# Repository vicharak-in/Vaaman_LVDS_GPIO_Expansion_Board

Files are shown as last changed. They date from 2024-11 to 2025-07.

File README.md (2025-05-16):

# Vaaman_UART_Expansion_Board

GPIO HAT 1:

LVDS RX and TX from Vaaman configure as a GPIO of this HAT. total 80 GPIOs are availabe in HAT can be configure form Vaaman LVDS.

voltage level of signal: 3.3V

Level translator Part number: TXB0108DQSR

LVDS connector part number: DF40C-60DP-0.4V(51)

Vaaman and HAT Connection: Flex cable

Power input: Vaaman Header 





NOT tested Yet(GPIO HAT 1).

GPIO HAT 2:

LVDS RX and TX from Vaaman configure as a GPIO of this HAT. total 80 GPIOs are availabe in HAT can be configure form Vaaman LVDS.

voltage level of signal: 3.3V & 1.8V (using jumper)

Level translator Part number: TXB0108DQSR

LVDS connector part number: DF40C-60DP-0.4V(51)

Vaaman and HAT Connection: Flex cable

Power input: Vaaman Header or Type-C 





Power up instructions:

Vaaman LVDS GPIO HAT can Power by two Options: 

Option 1: Using Female to Female Jumper From Vaaman Header to GPIO Hat Header

Vaaman Header 5V and GND:



GPIO HAT Header:



Working Properly.

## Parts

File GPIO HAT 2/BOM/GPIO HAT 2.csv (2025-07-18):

Designator | Description | Value | Manufacturer Part Number | Type | Vicharak-PN | Footprint | Case/Package | Quantity
C10, C11, C19, C20, C21, C22, C23, C24, C25, C26, C27, C28, C29, C30, C31, C32, C33, C34, C35, C36, C37, C38 | 100nF, 25V, X5R, ±10%, 0402, Multilayer Ceramic Capacitor - SMD/SMT | 100nF | CL05A104KA5NNNC | Capacitor | V001480 | CAP_0402 | 402 | 22
C2, C3, C9, C13, C14, C6, C7, C17, C18 | 100nF, 25V, X7R, ±10%, 0603, Multilayer Ceramic Capacitors | 100nF | CL10B104KA8NNNC | Capacitor | V001603 | CAP_0603 | 603 | 9
C1, C8, C12, C5, C16 | 1uF, 25V, X5R, ±10%, 0603, Multilayer Ceramic Capacitor - SMD/SMT | 1uF | CL10A105KA8NNNC | Capacitor | V001450 | CAP_0603 | 603 | 5
C4, C15 | 100pF, 50V, NP0, ±5%, 0402, Multilayer Ceramic Ca...tors MLCC - SMD/SMT | 100pF | CC0402JRNPO9BN101 | Capacitor | V000090 | CAP_0402 | 402 | 2
R8, R9, R10, R11, R12, R13, R14, R15, R16, R17, R7 | 10KOhm, ±1%, 62.5mW, 0402, Chip Resisto | 10K | 0402WGF1002TCE | Resistor | V000011 | RES_0402 | 402 | 11
R1, R6 | 100KOhm, ±1%, 1/16W, 0402, Resistor | 100K | RC0402FR-07100KL | Resistor | V000404 | RES_0402 | 402 | 2
R2 | 22.1KOhm, ±1%, 62.5mW, 0402, Chip Resisto | 22.1K | 0402WGF2212TCE | Resistor | V000235 | RES_0402 | 402 | 1
R3 | 20KOhm, ±1%, 62.5mW, 0402, Resistor | 20K | 0402WGF2002TCE | Resistor | V000408 | RES_0402 | 402 | 1
R5 | 4.99KOhm, ±1% 62.5mW, 0402, Chip Resistor | 4.99K | 0402WGF4991TCE | Resistor | V000258 | RES_0402 | 402 | 1
R7 | 49.9KOhm, ±1%, 62.5mW, 0402, Resisto | 49.9K | 0402WGF4992TCE | Resistor | V001610 | RES_0402 | 402 | 1
R18, R19 | 5.1KOhm, ±1%, 62.5mW, 0402, Resistor | 5.1K | 0402WGF5101TCE | Resistor | V000399 | RES_0402 | 402 | 2
L1, L2 | 3.3uH, 40mOhm, 2.4A, 3.3A, 30%, Power Inductors | 3.3uH | GCNR4030-3R3NC | Inductor | V001278 | IND | IND | 2
U4, U5, U6, U7, U8, U9, U10, U11, U12, U13 | Voltage Level Translator Bidirectional 1 Circuit 8 Channel 100Mbps 20-USON (4x2) |  | TXB0108DQSR | IC | V001766 | USON20 | USON20 | 10
U1, U3 | Buck, Input 2.5V~5.5V, 1A, SOT-23-5, DC-DC Converter |  | SY8088IAAC | IC | V001502 | SOT23-5 | SOT23-5 | 2
U2 | 1.6-V to 5.5-V, 4-A Low IQ Power Mux With Manual and Priority Switchover |  | TPS2117 | IC | V001701 | SOT8 | SOT-8 | 1
J1 | Type-C 5A USB 3.1 1 260? Surface Mount 6P Female ...5? Gold Copper Alloy SMD USB Connector |  | U262-061N-4BVC11 | Connector | V000570 |  |  | 1
J3, J4 | 0.4mm 2 60 -35?~+85? Brick nogging male 300mA SMD...m Mezzanine Connector |  | DF40C-60DP-0.4V(51) | Connector | V000472 | DF40C-60DP-0.4V(51) |  | 2
J1, J2, J3, J4, J5, J6, J7, J8, J9, J10, J11, J12, J13, J14, J15, J16, J17, J18, J19, J20 | Connector Header Through Hole 6 position 0.100" (2.54mm) |  | 2541WV-06P | Connector | V002463 | 01x06 HEADER |  | 20
JM1, JM2, JM3, JM4, JM5 |  | PinHeader_1x03_P2.54mm_Vertical | 2541WV-03P | Connector | V002464 | 01x03 HEADER |  | 5
J24 | Gold Through Hole Pin Header 2.54mm 4Pin 2x2Pin |  | 2541WV-2x02P | Connector | V002465 | 02X02 HEADER |  | 1
PCB | GPIO HAT BLANK PCB V1.3 |  |  |  | V002371 |  |  | 1

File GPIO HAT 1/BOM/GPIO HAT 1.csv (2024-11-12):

Id | Designator | Footprint | Quantity | Designation | Supplier and ref
1 | J2,J14,J1,J9,J17,J13,J10,J7,J12,J15,J8,J16,J5,J19,J3,J11,J4,J20,J18,J6 | 01x05 Header 2.54mm | 20 | Conn_01x05
2 | R6,R3,R10,R8,R5,R1,R7,R4,R9,R2 | RES0402_10K | 10 | 10K
3 | U10,U6,U7,U1,U2,U9,U8,U5,U4,U3 | TXB0108DQSR | 10 | TXB0108DQSR
4 | J23,J24 | 2x20 header | 2 | 2.54-2*20PPC104
5 | ,,, | HOLEE | 4 | HOLE
6 | C9,C6,C14,C19,C18,C4,C10,C3,C5,C20,C15,C16,C8,C1,C11,C2,C7,C12,C13,C17 | CAP0402 | 20 | 0.1uF
7 | J21,J22 | LVDS2 | 2 | ~

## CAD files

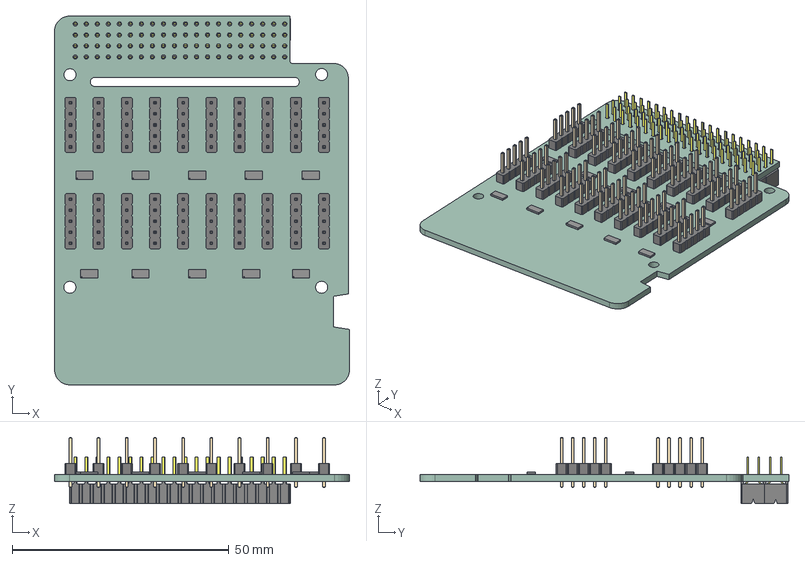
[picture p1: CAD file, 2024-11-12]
GPIO HAT 1/GPIO HAT 1.step
68.0 x 85.0 x 15.3 mm
PinHeader_1x05_P254mm_Vertical x 20
DQS20 x 10
ces-120-02-g-d x 2
_autosave-VAAMAN_KICAD_PCB

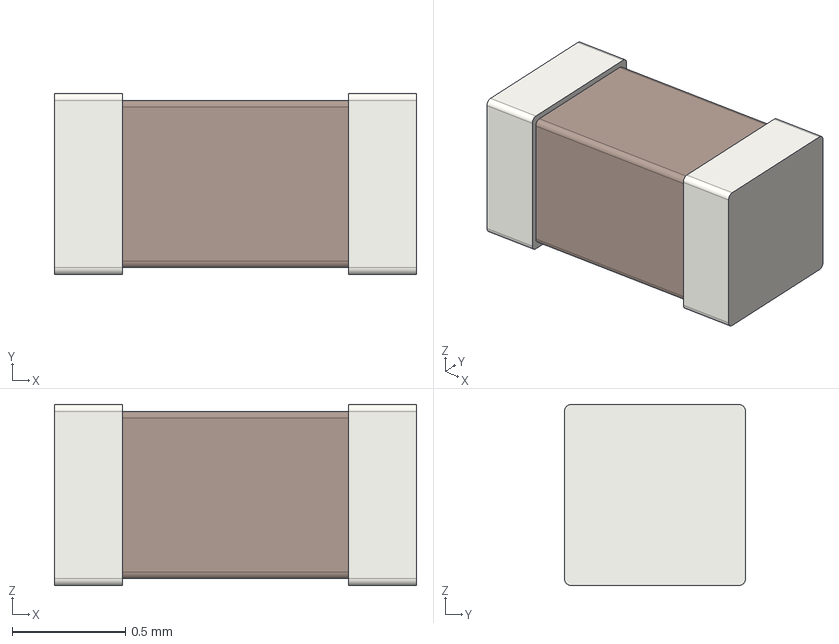
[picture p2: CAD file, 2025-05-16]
GPIO HAT 2/Component 3D File/C_0603_1608Metric.step
1.60 x 0.8 x 0.8 mm

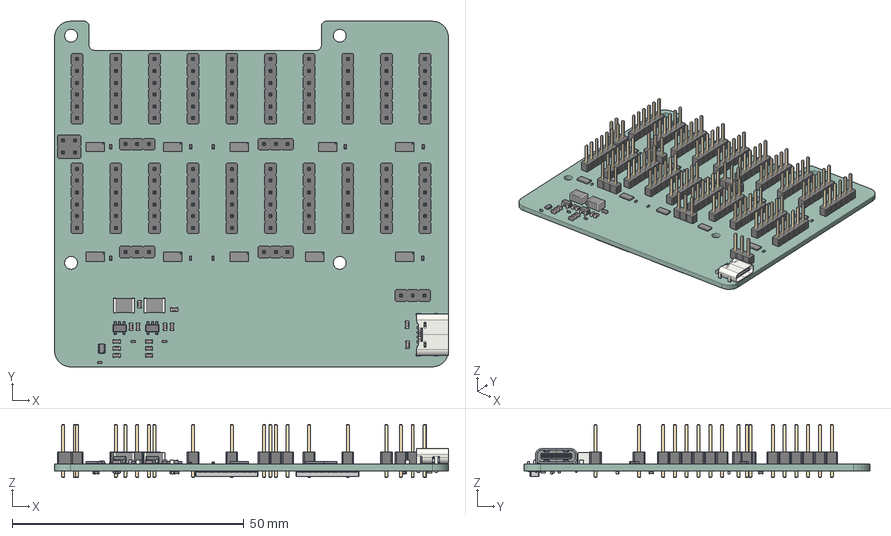
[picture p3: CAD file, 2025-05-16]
GPIO HAT 2/VAAMAN KICAD 2.step
85.0 x 74.6 x 11.5 mm
R_0402_1005Metric x 13
C_0603_1608Metric x 14
DQS20 x 10
C_0402_1005Metric x 24
PinHeader_1x06_P254mm_Vertical x 20
PinHeader_1x03_P254mm_Vertical x 5
L_1812_4532Metric x 2
PinHeader_2x02_P254mm_Vertical
SOT_23_5 x 2
USB_C_Receptacle_GCT_USB4125-xx-x_6P_TopMnt_Horizontal
TPS2116DRLR
DF40C-40DP-0.4V.1 x 2
GPIO HAT 2_PCB

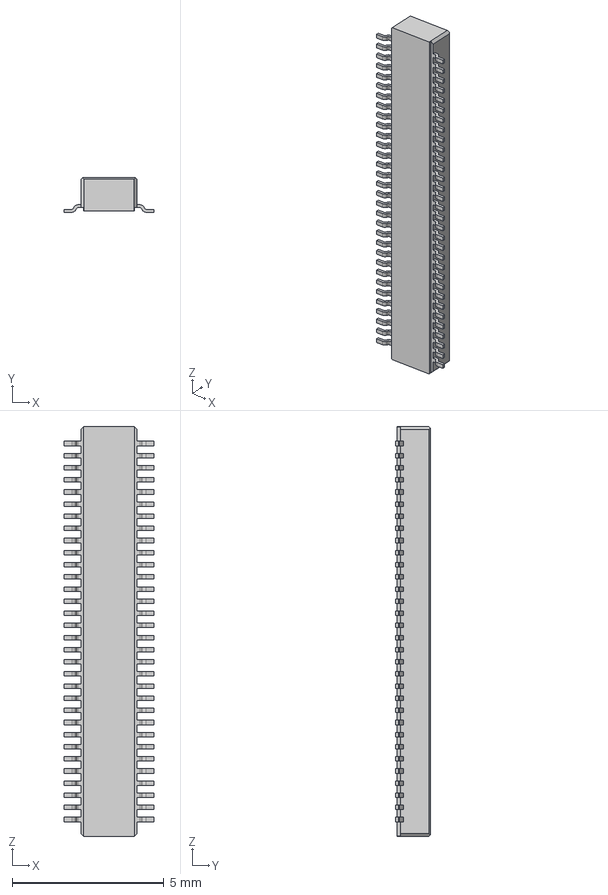
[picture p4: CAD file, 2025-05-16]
GPIO HAT 2/Component 3D File/DF40C-60DP.stp
2.97 x 1.14 x 13.5 mm

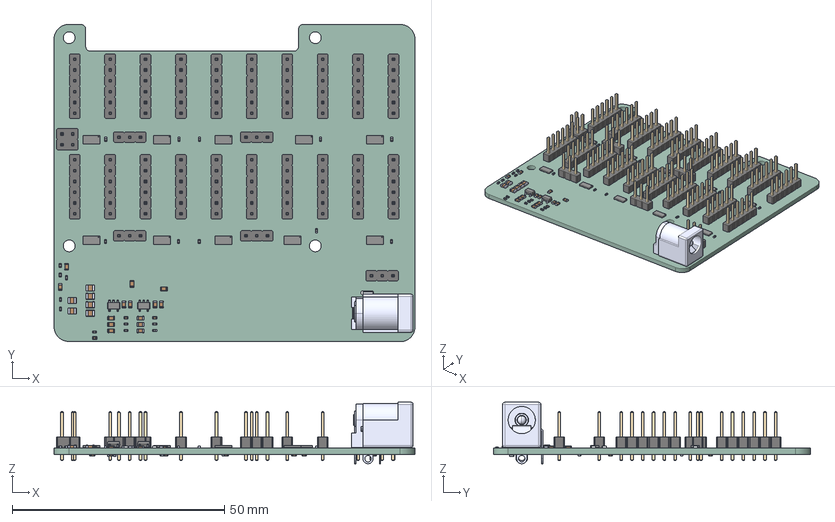
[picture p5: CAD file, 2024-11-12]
GPIO HAT 2/GPIO HAT 2.step
85.0 x 74.7 x 14.5 mm
SR0402JR-7W10RL x 22
CL10B105MO8NNWC x 14
DQS20 x 10
PinHeader_1x06_P254mm_Vertical x 20
PinHeader_1x03_P254mm_Vertical x 5
VJ0805A221KXRAT5Z x 6
VJ0402D180JXBAJ x 24
PinHeader_2x02_P254mm_Vertical
MAX6316LUK29BX_V+T x 2
VAAMAN KICAD 2_PCB

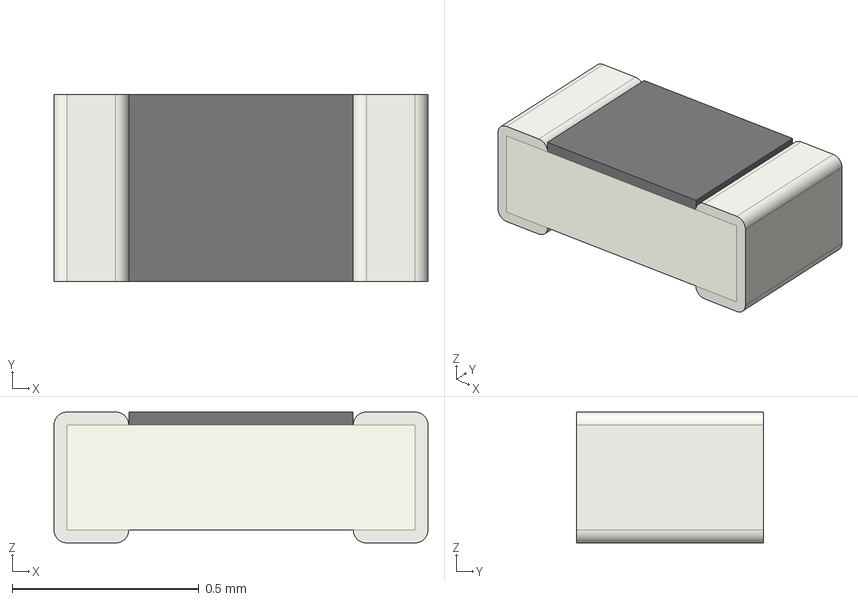
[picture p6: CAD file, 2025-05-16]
GPIO HAT 2/Component 3D File/R_0402_1005Metric.step
1.00 x 0.5 x 0.35 mm

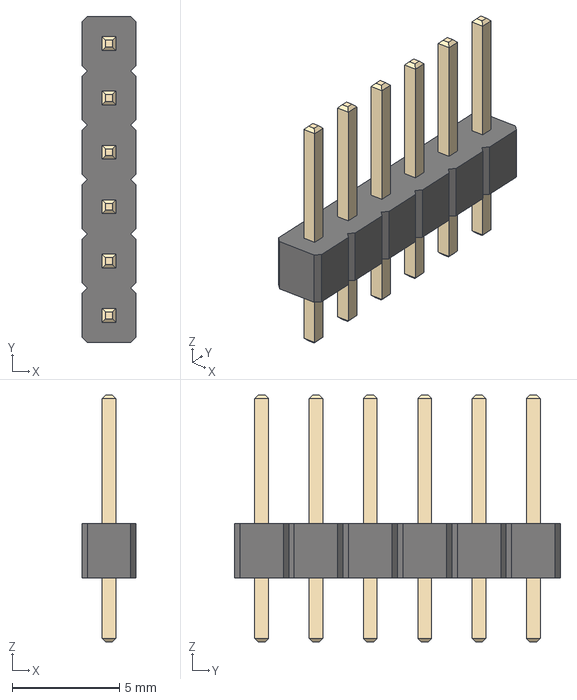
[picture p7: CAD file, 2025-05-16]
GPIO HAT 2/Component 3D File/PinHeader_1x06_P2.54mm_Vertical.step
2.54 x 15.2 x 11.5 mm

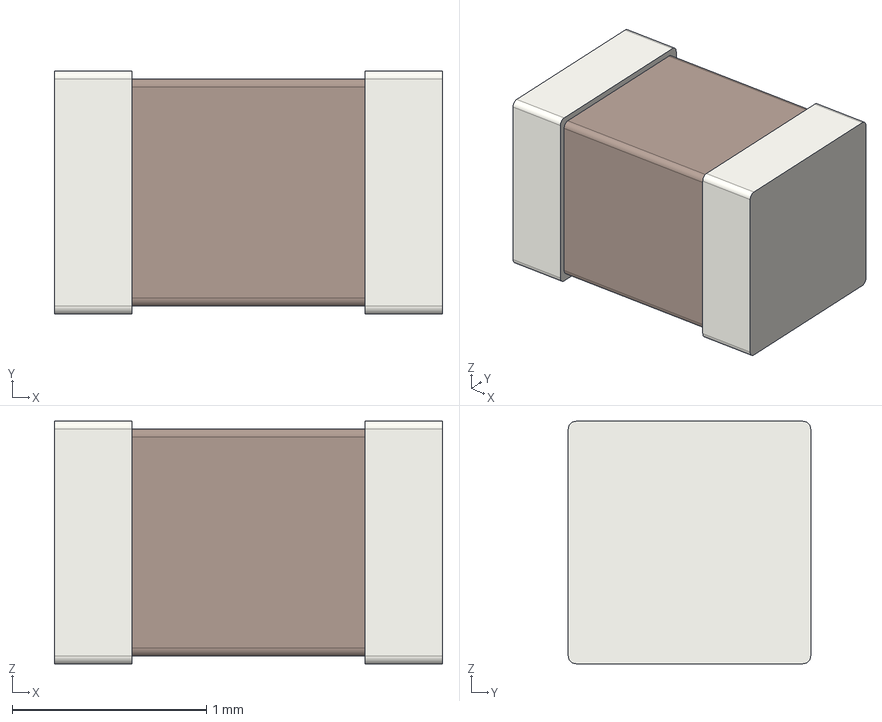
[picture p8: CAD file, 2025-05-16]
GPIO HAT 2/Component 3D File/C_0805_2012Metric.step
2.00 x 1.25 x 1.25 mm

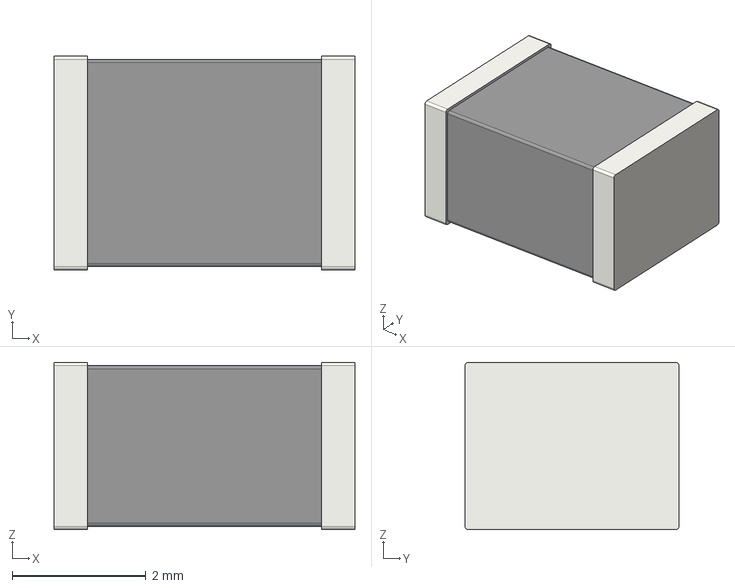
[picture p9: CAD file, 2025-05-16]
GPIO HAT 2/Component 3D File/L_1812_4532Metric.step
4.50 x 3.20 x 2.50 mm

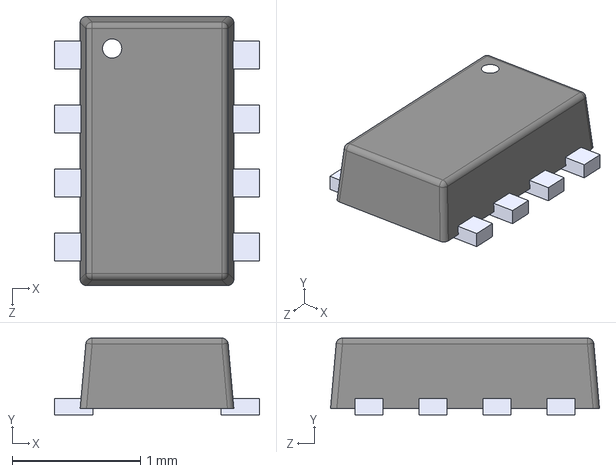
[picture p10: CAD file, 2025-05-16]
GPIO HAT 2/Component 3D File/TPS2117DRLR.STEP
1.60 x 0.6 x 2.10 mm

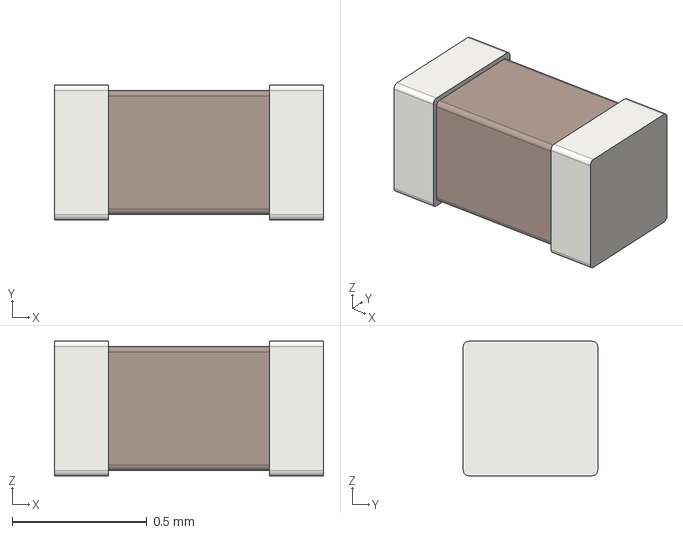
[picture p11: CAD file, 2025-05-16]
GPIO HAT 2/Component 3D File/C_0402_1005Metric.step
1.00 x 0.5 x 0.5 mm

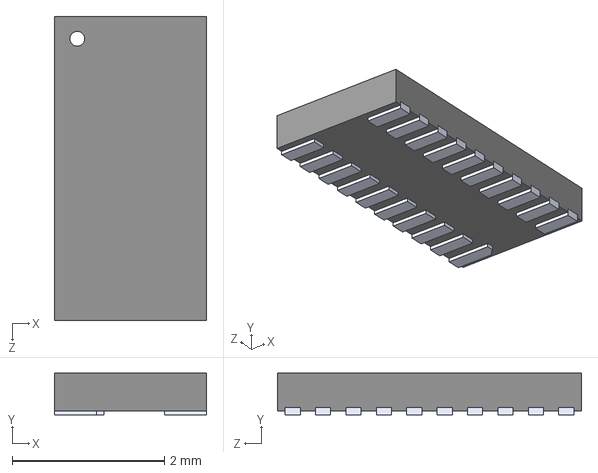
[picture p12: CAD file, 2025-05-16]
GPIO HAT 2/Component 3D File/TXB0108DQSR.STEP
2.00 x 0.55 x 4.00 mm

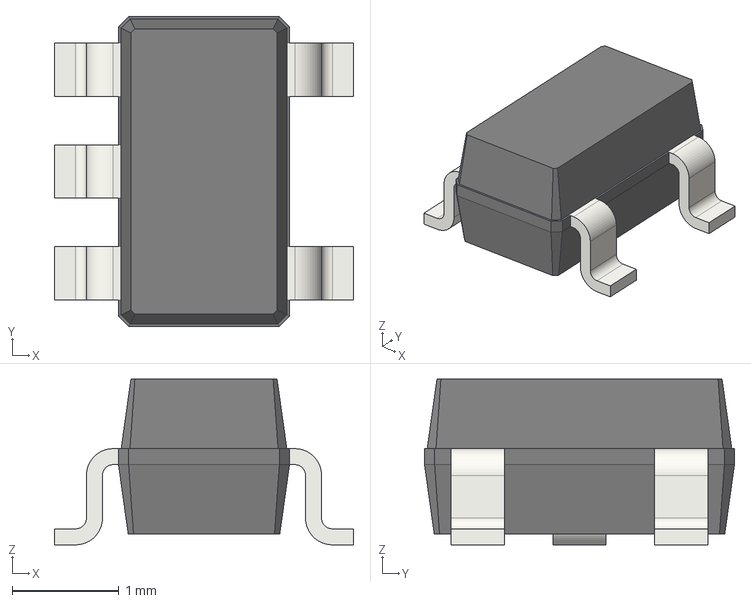
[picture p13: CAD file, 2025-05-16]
GPIO HAT 2/Component 3D File/SOT-23-5.step
2.80 x 2.90 x 1.55 mm

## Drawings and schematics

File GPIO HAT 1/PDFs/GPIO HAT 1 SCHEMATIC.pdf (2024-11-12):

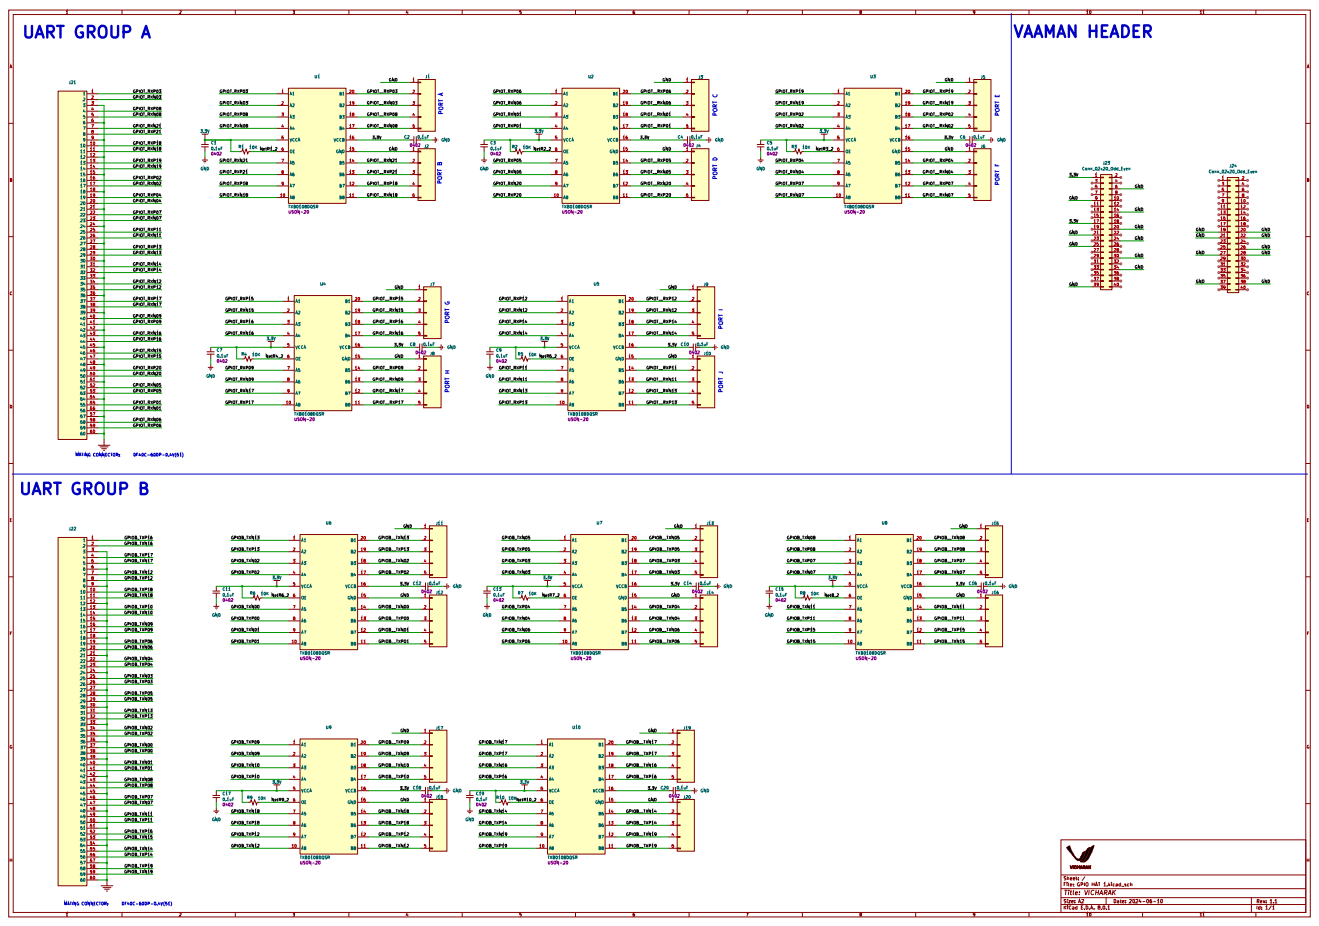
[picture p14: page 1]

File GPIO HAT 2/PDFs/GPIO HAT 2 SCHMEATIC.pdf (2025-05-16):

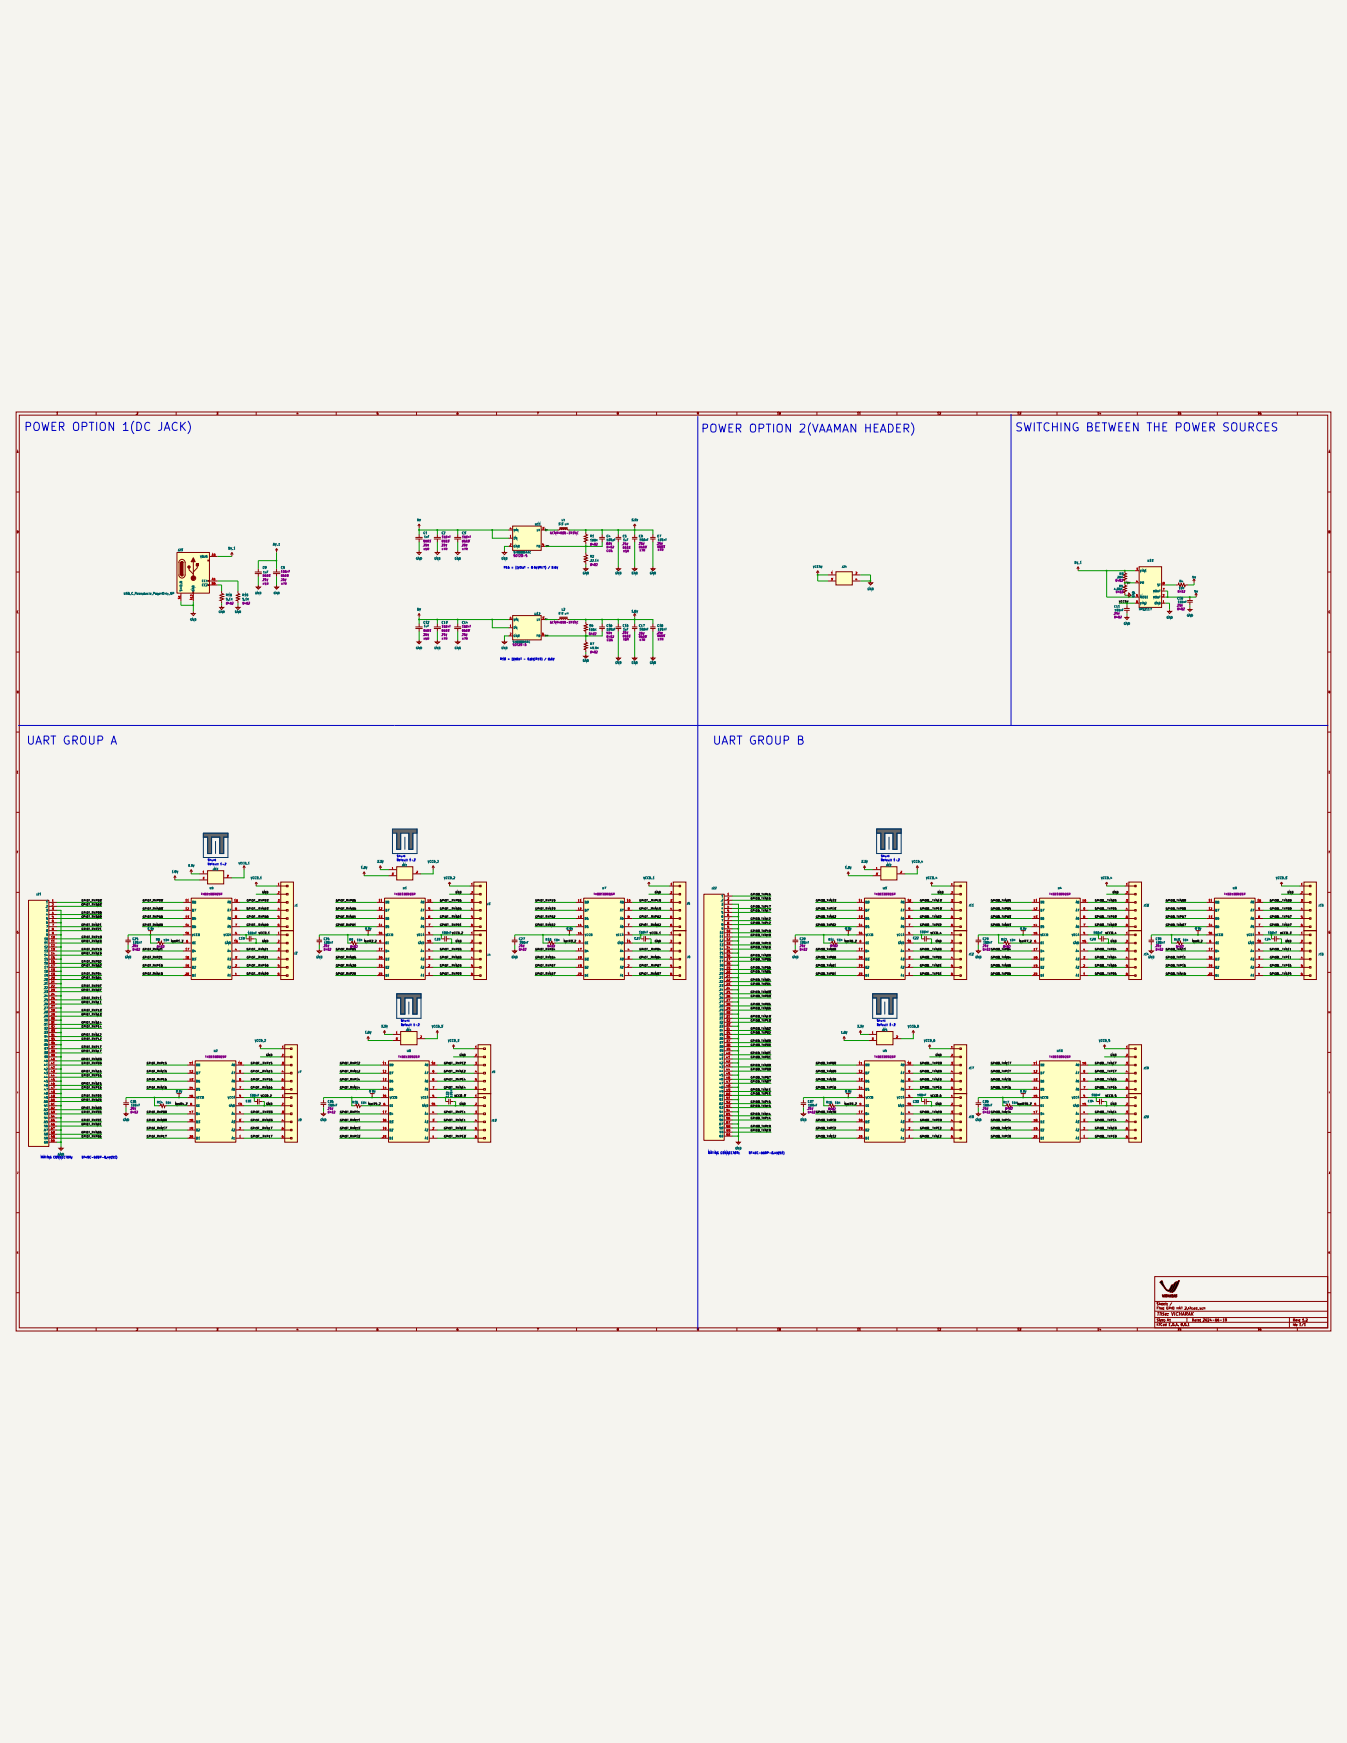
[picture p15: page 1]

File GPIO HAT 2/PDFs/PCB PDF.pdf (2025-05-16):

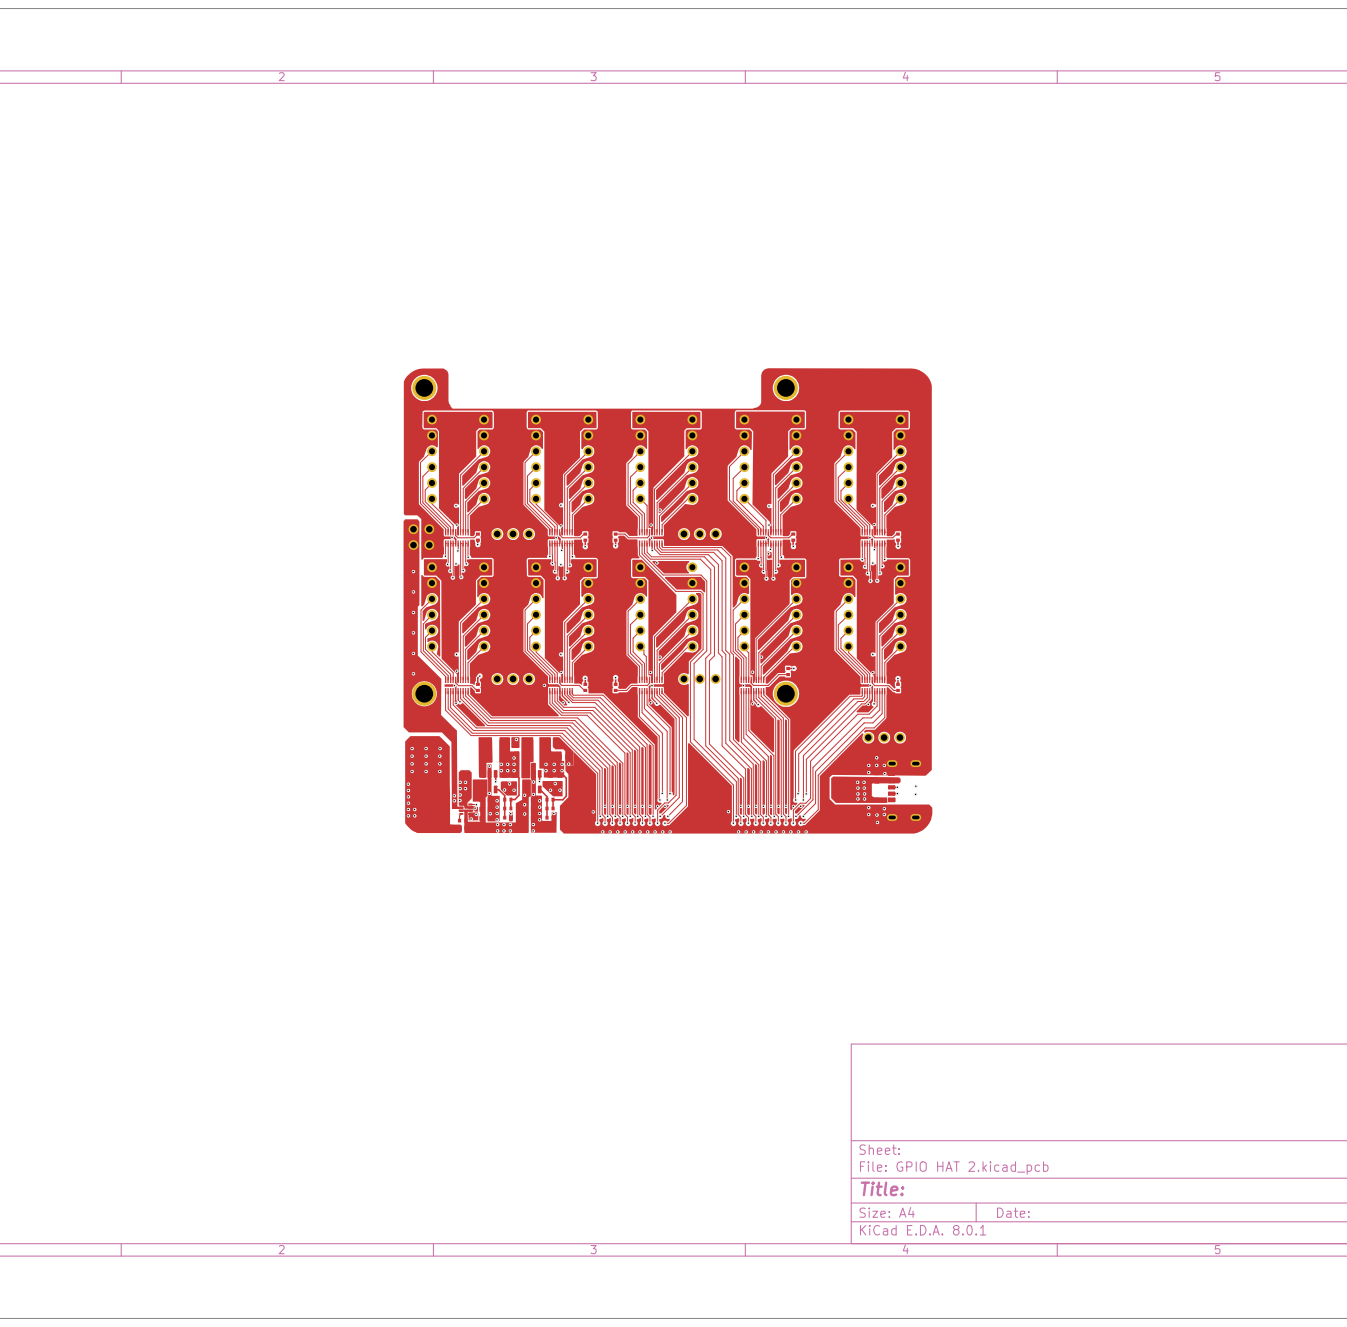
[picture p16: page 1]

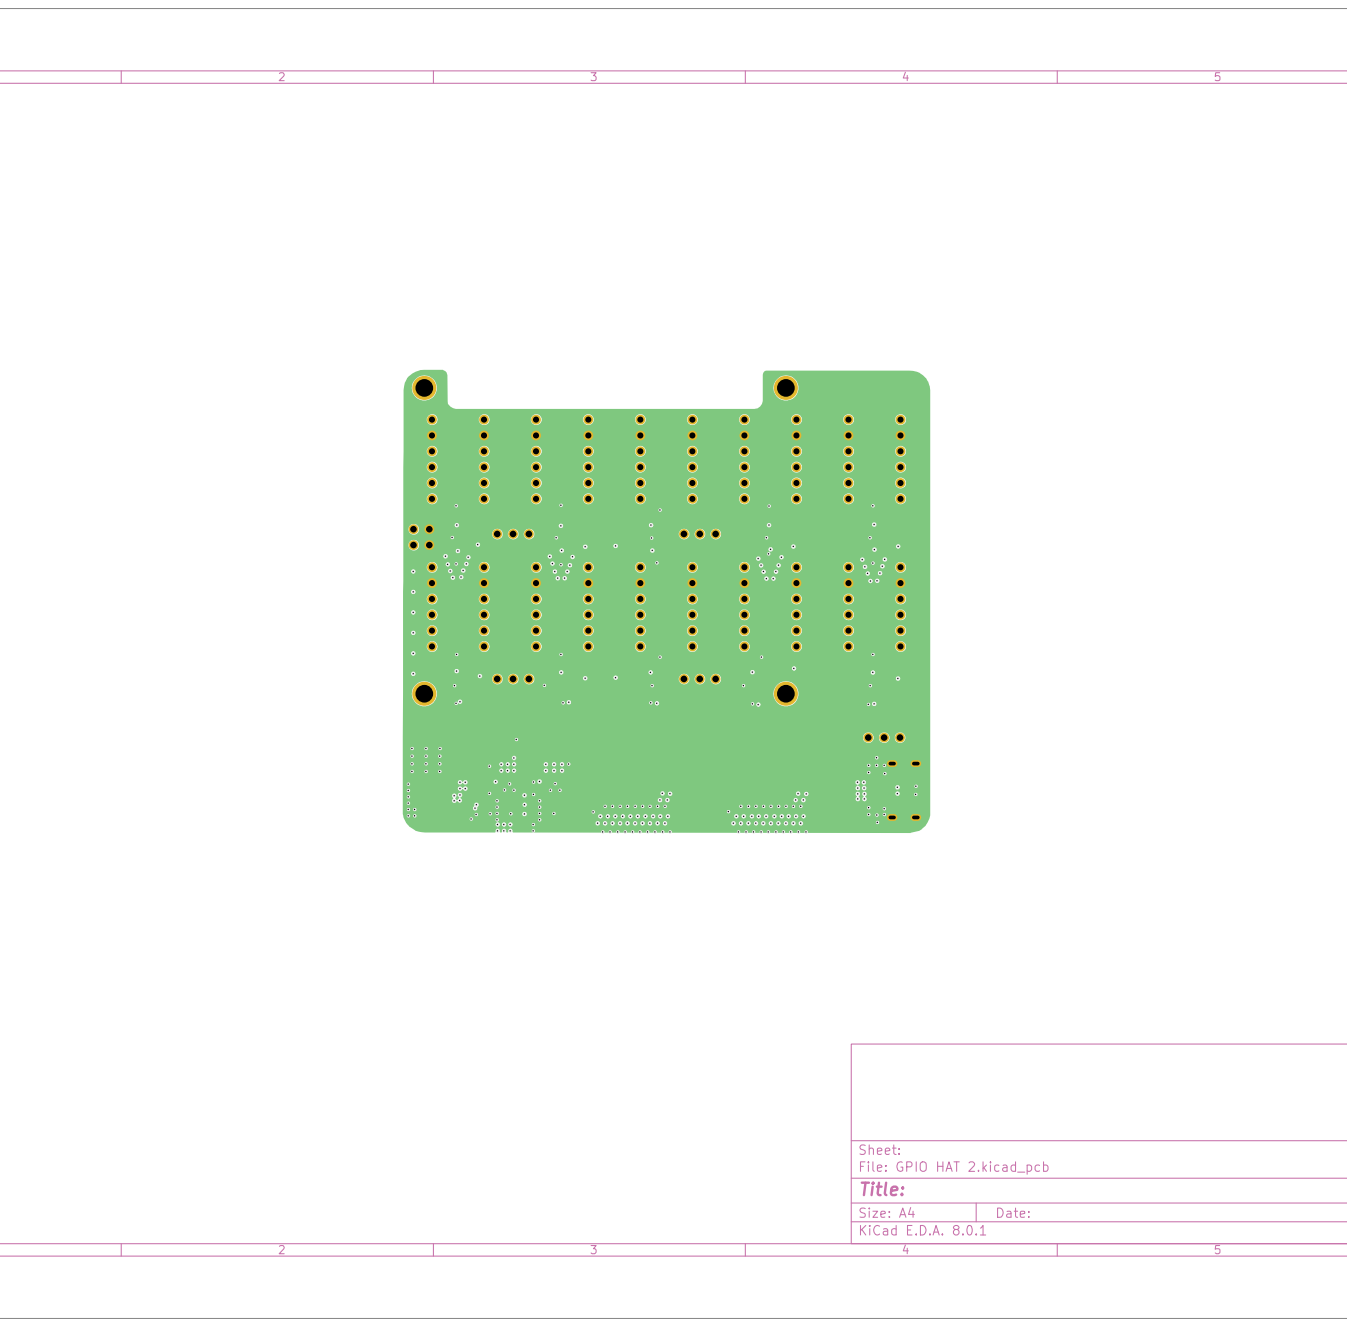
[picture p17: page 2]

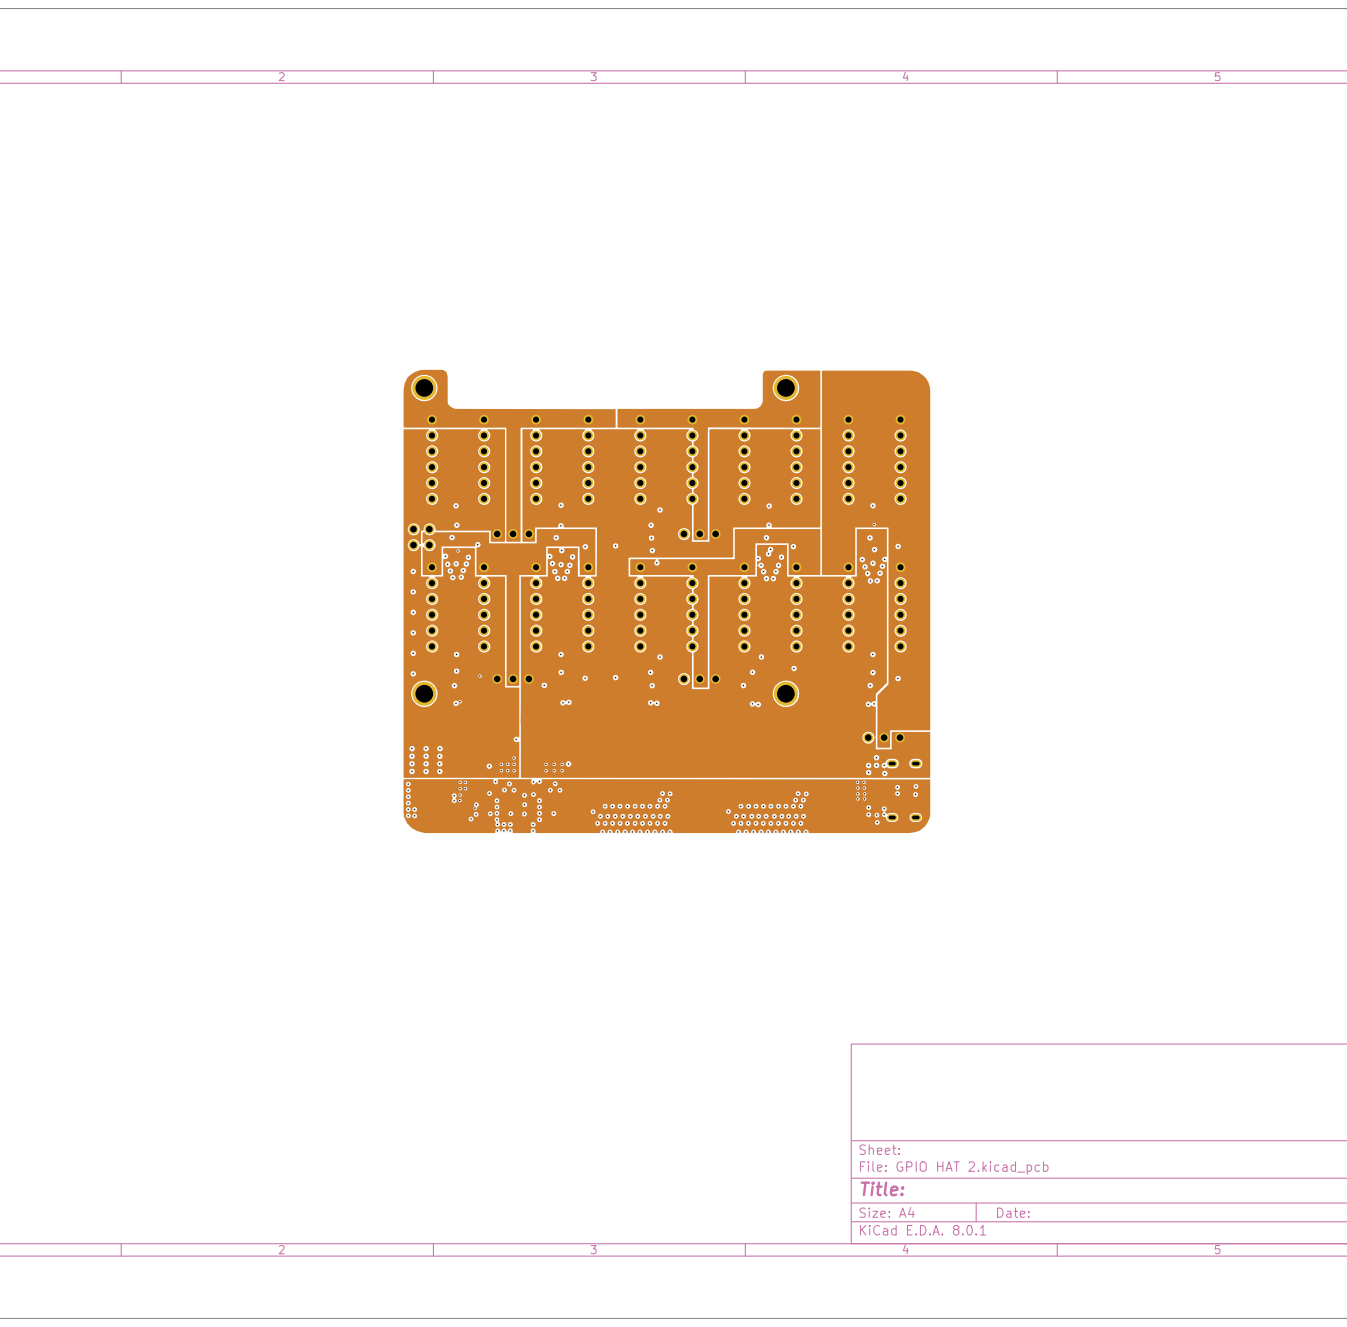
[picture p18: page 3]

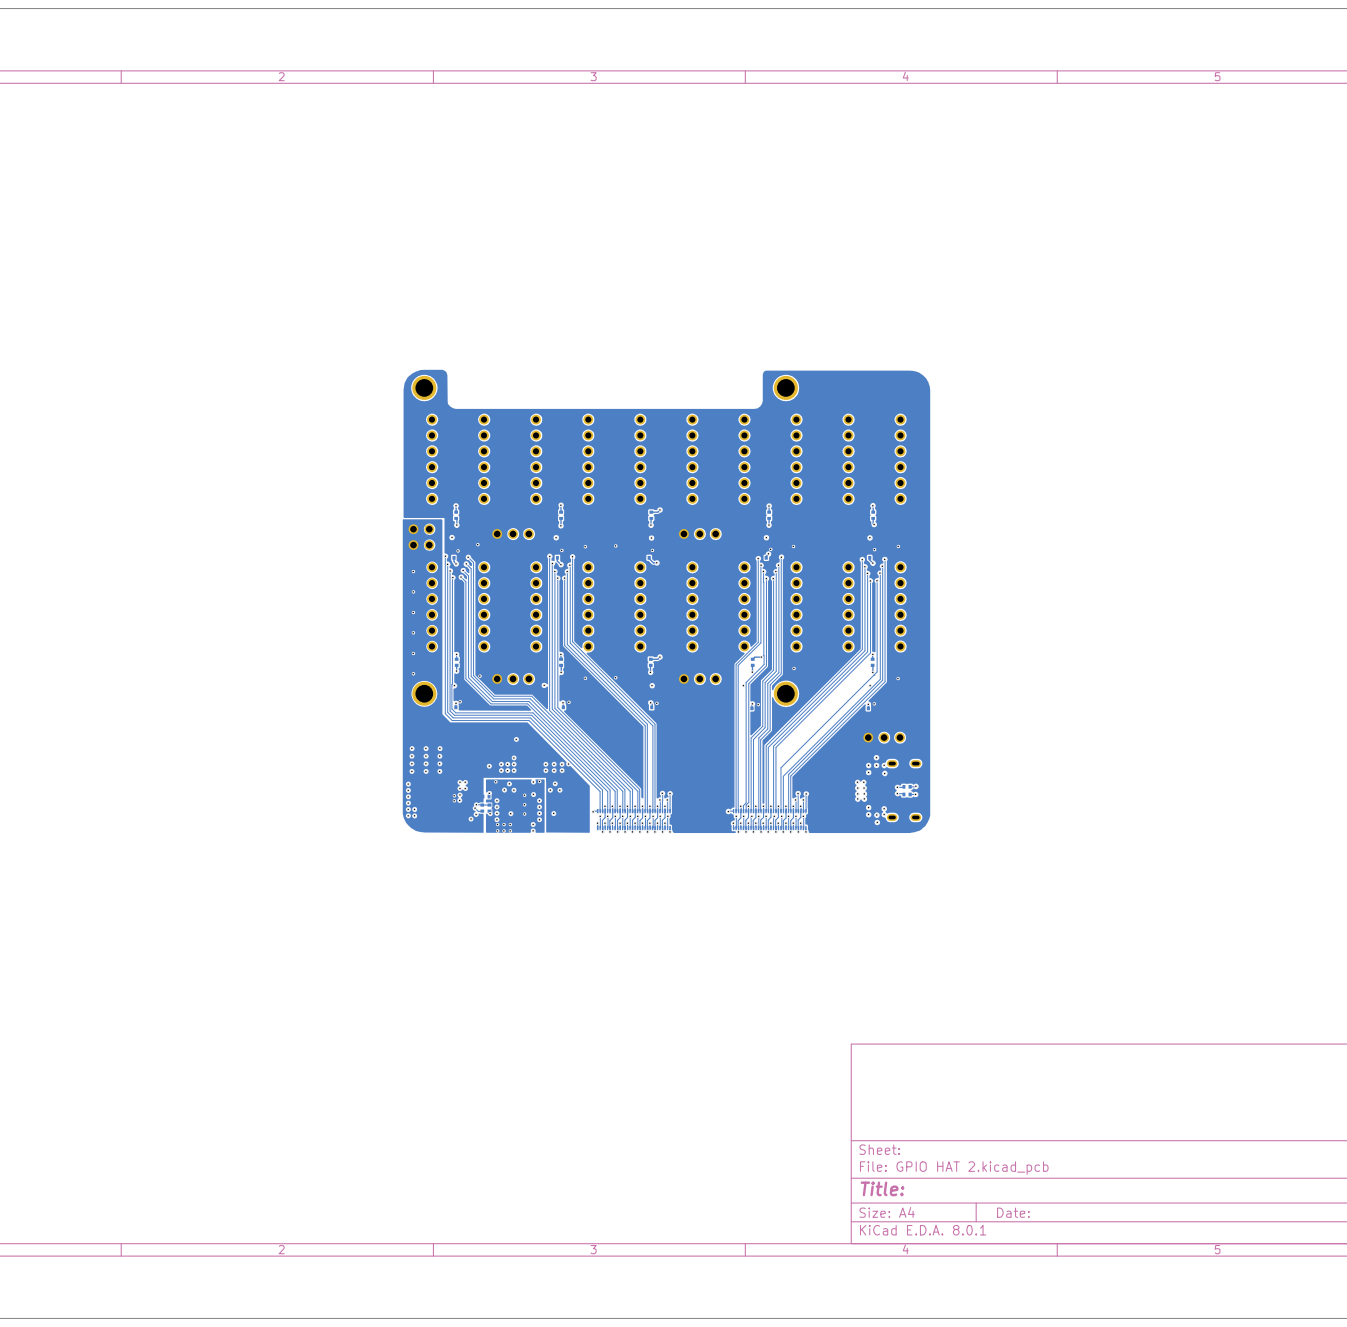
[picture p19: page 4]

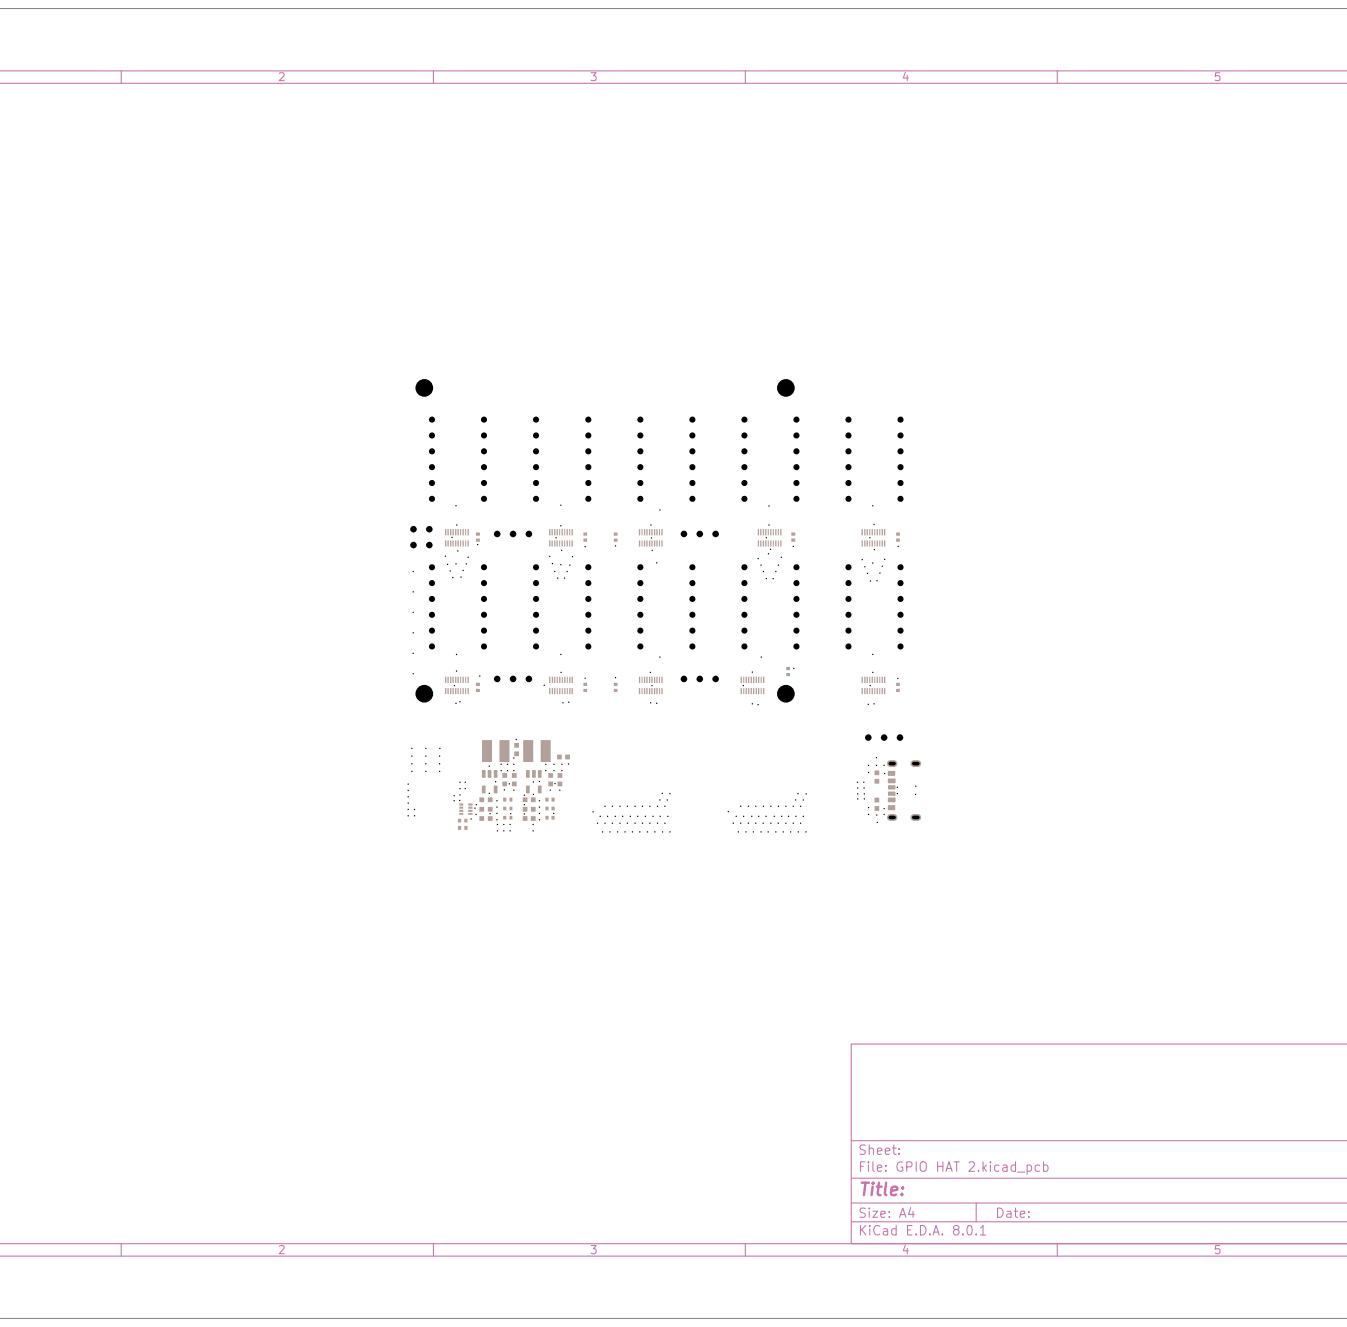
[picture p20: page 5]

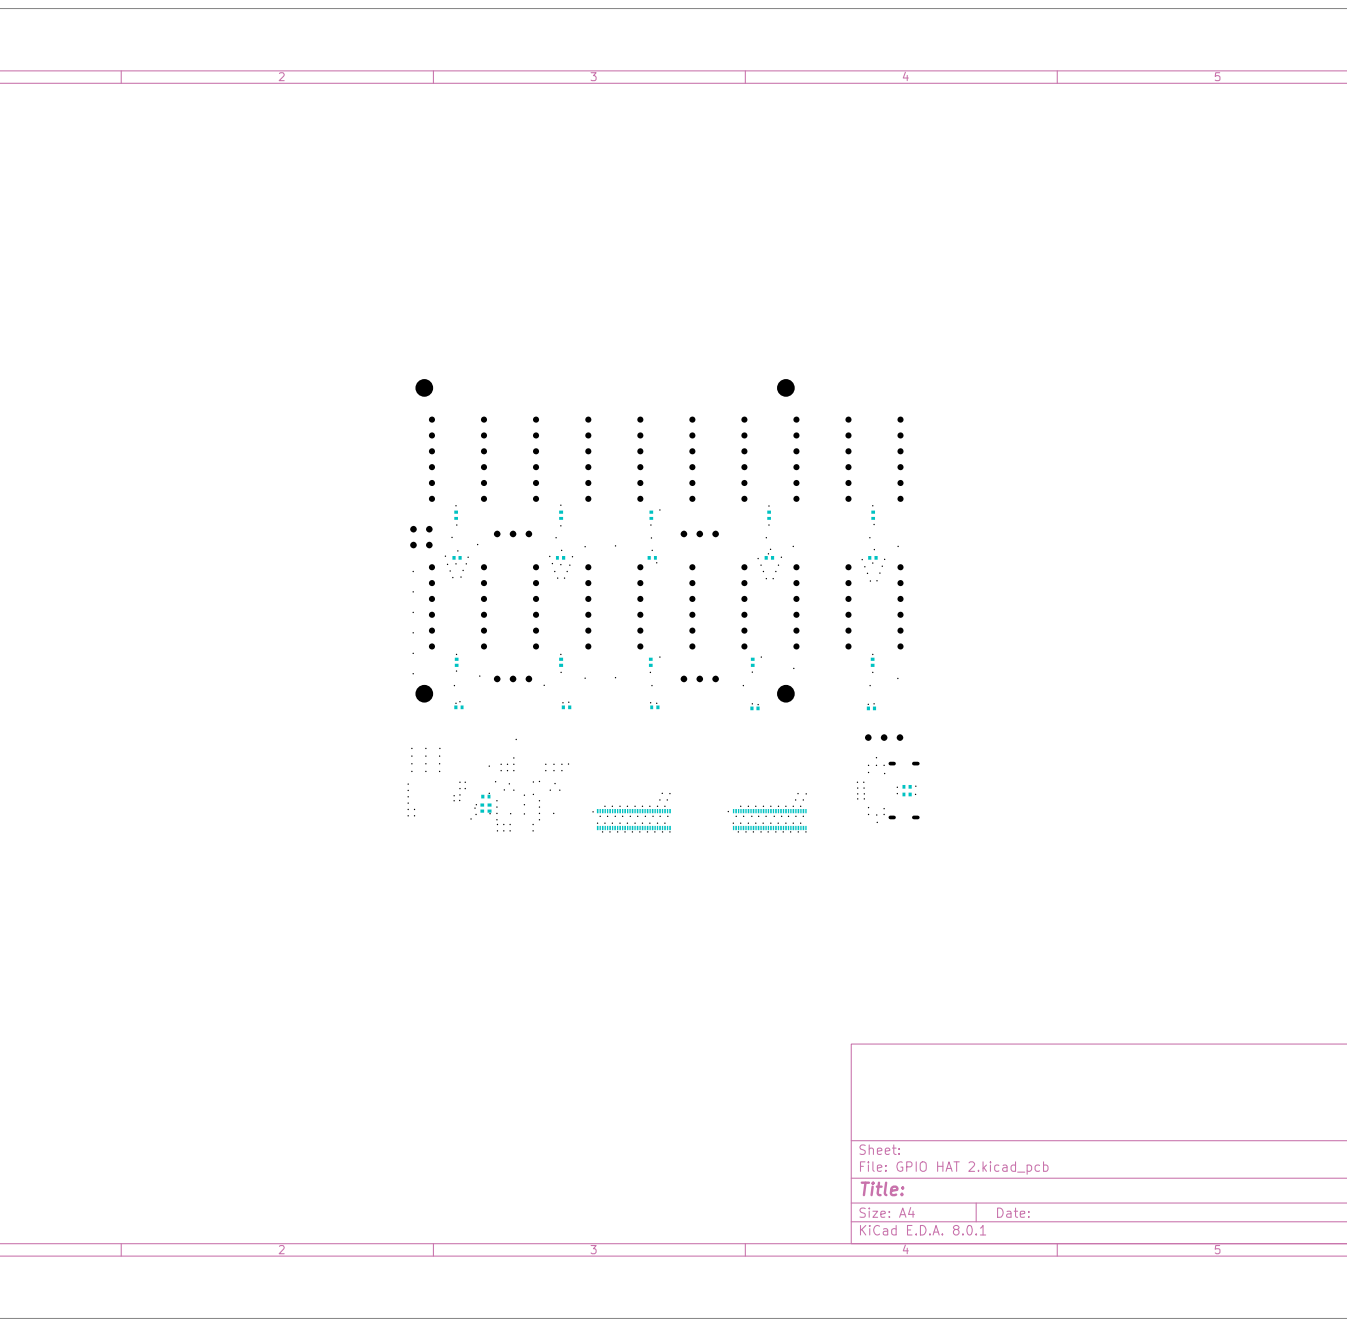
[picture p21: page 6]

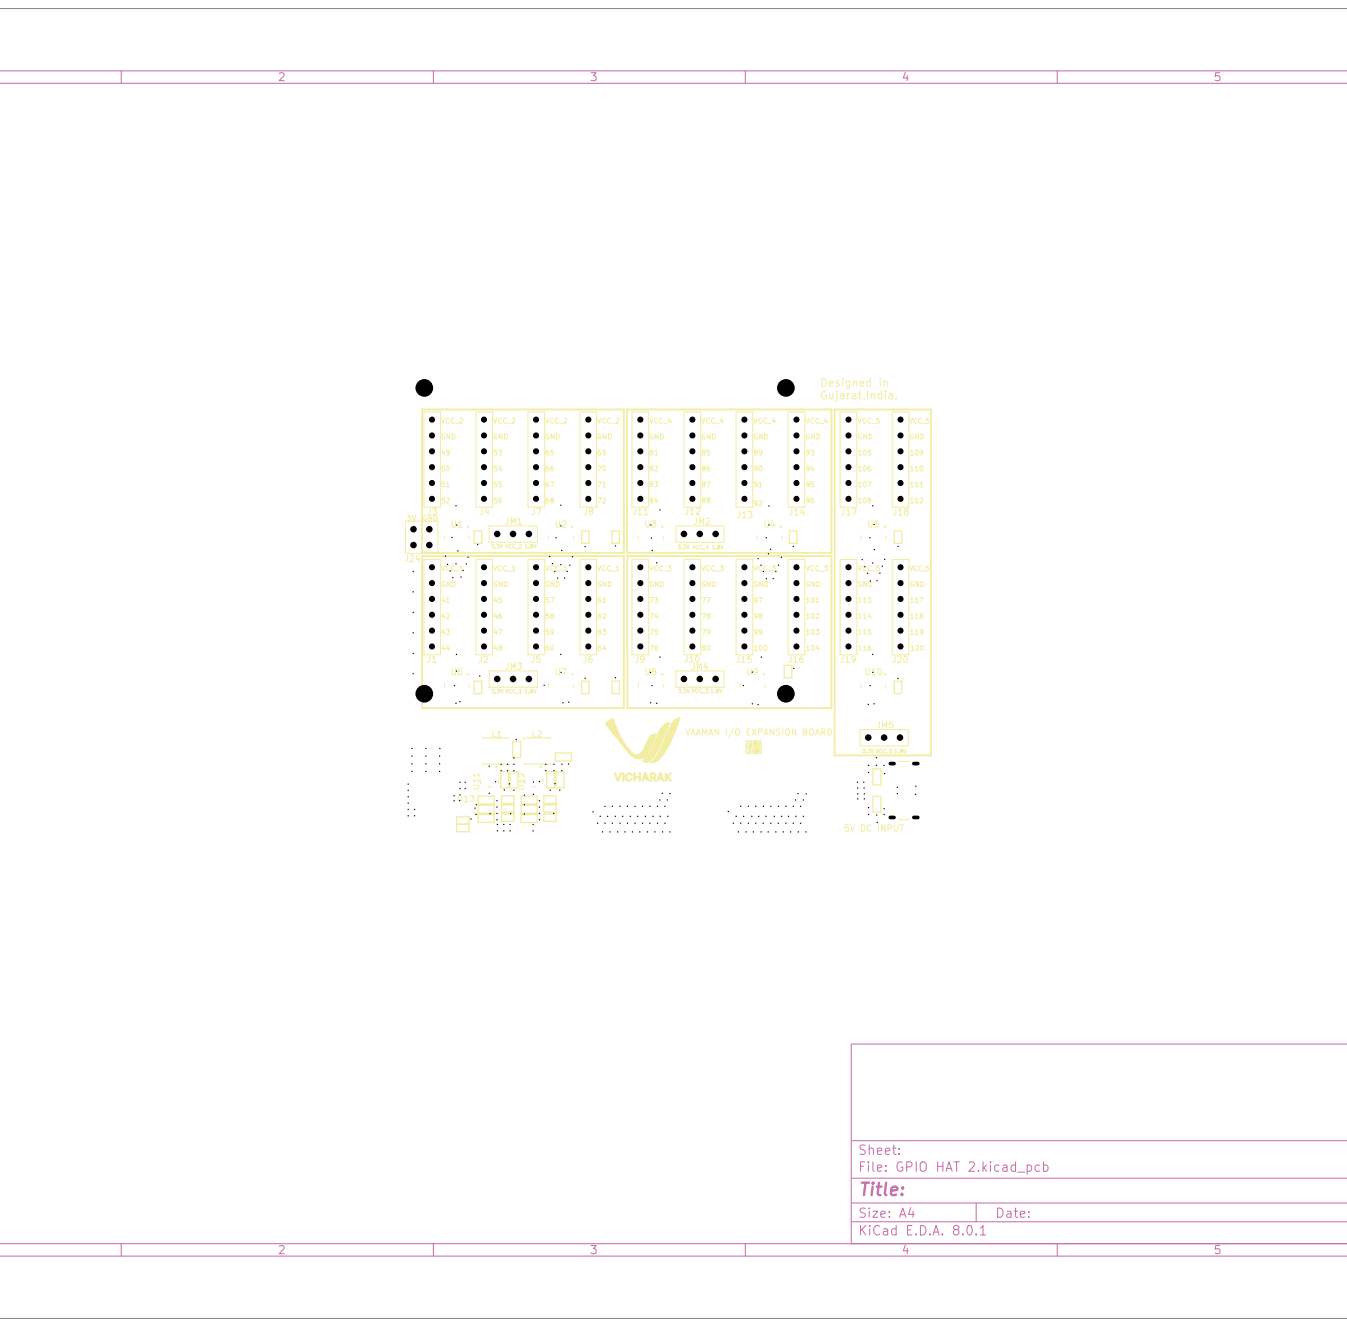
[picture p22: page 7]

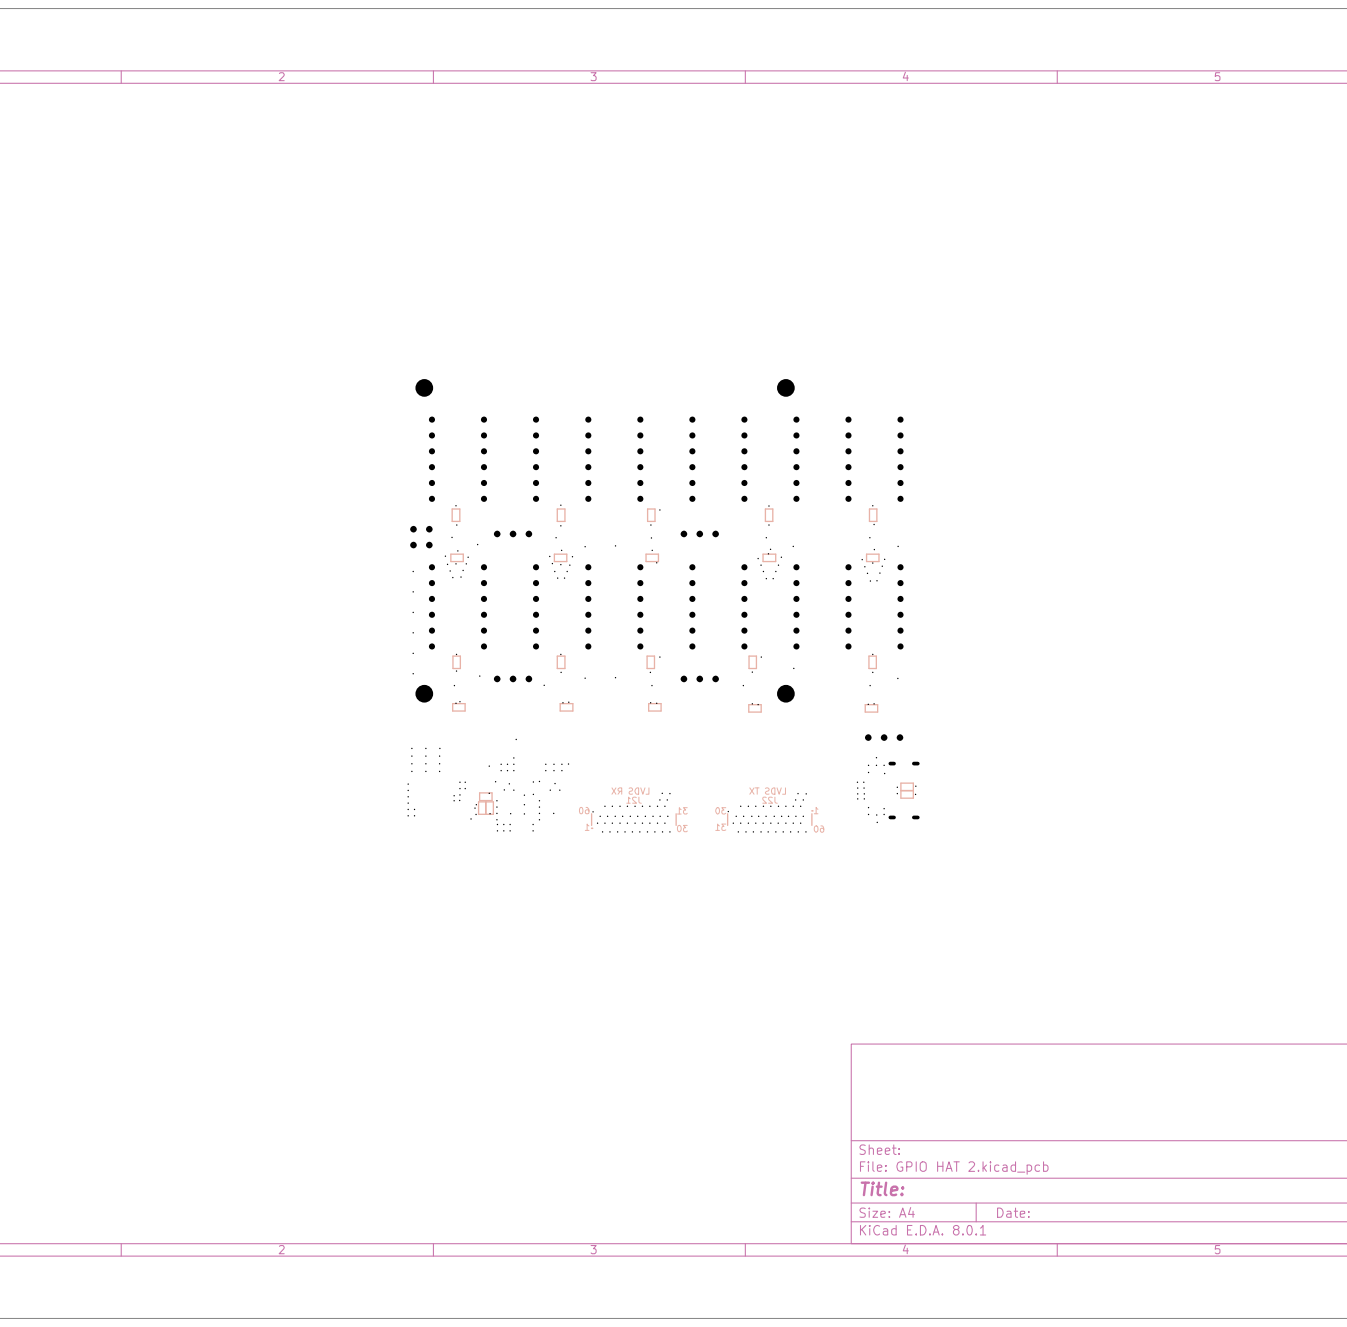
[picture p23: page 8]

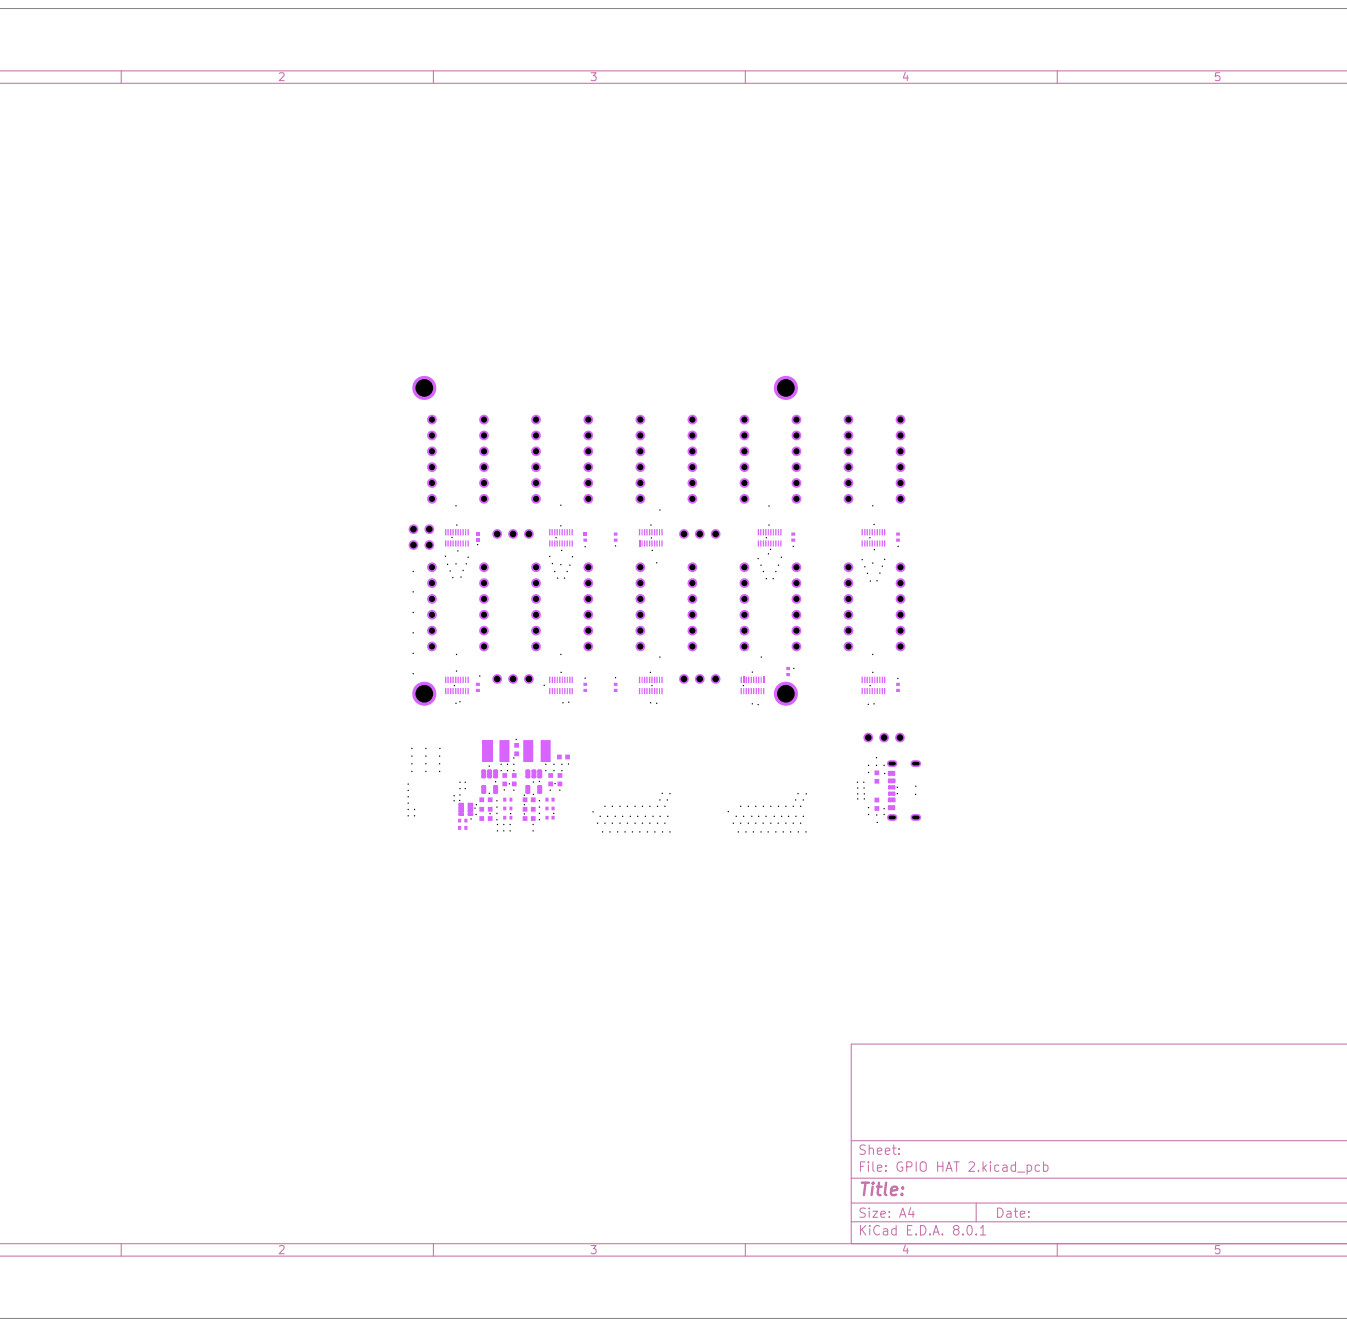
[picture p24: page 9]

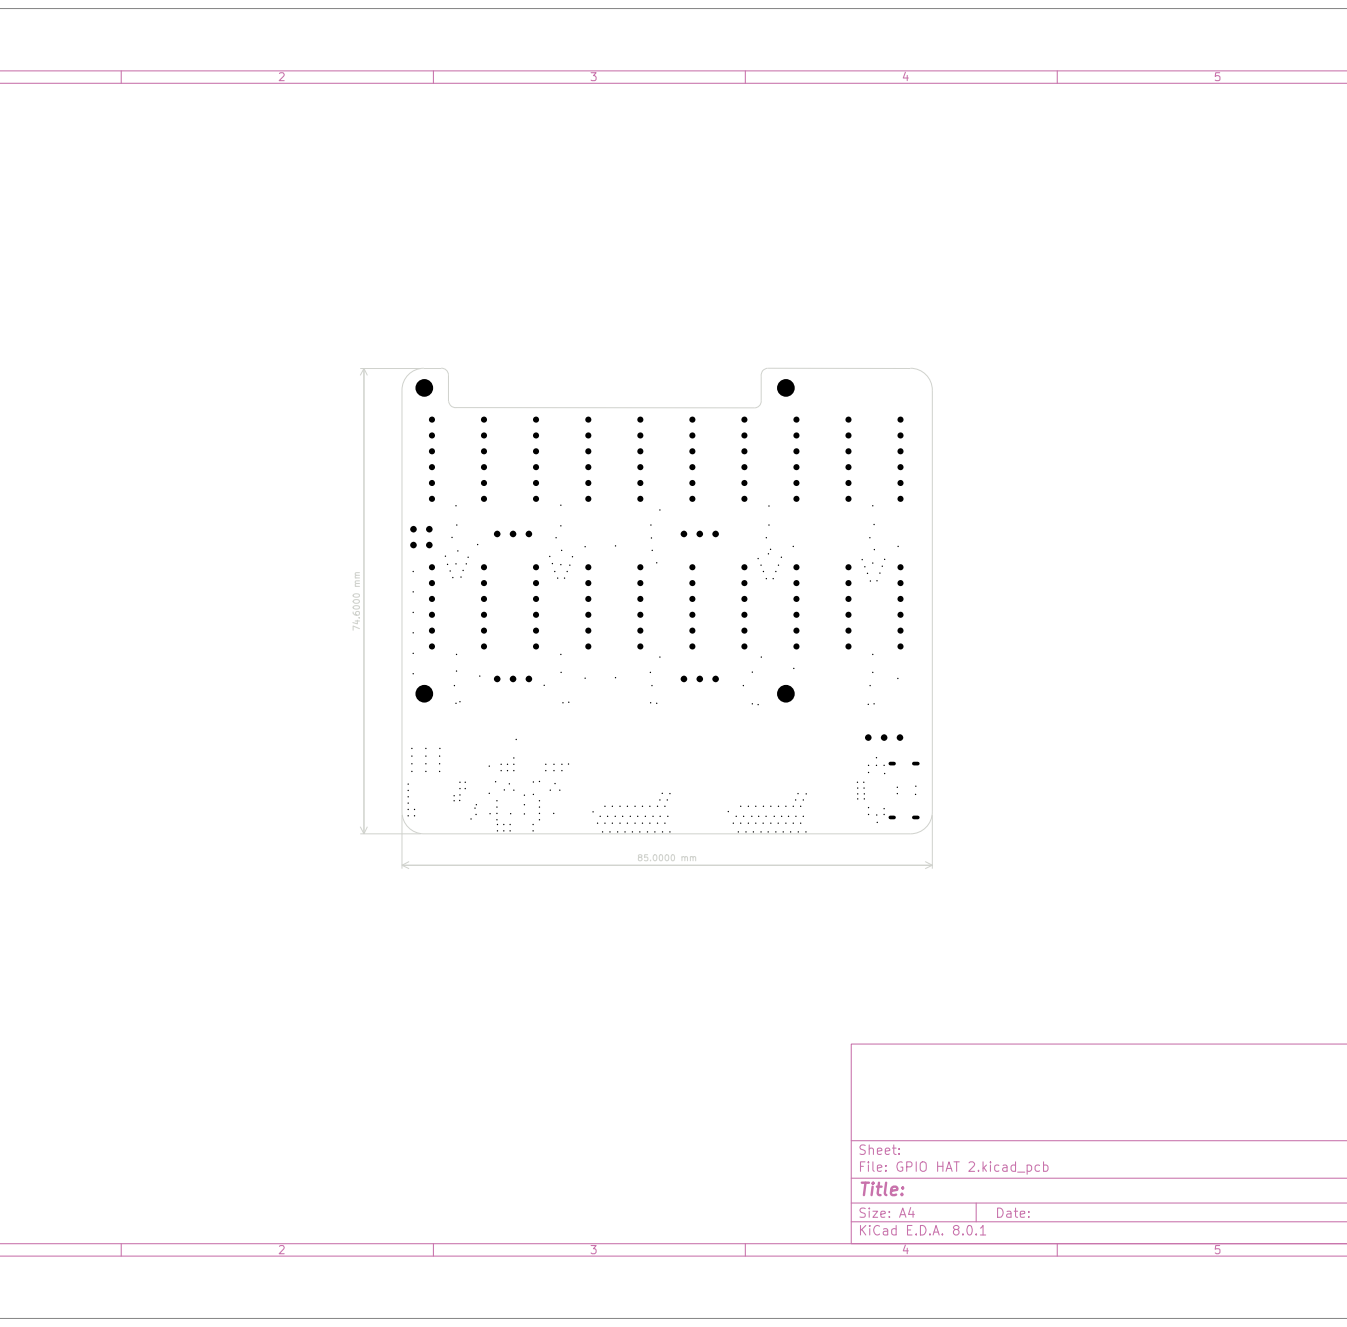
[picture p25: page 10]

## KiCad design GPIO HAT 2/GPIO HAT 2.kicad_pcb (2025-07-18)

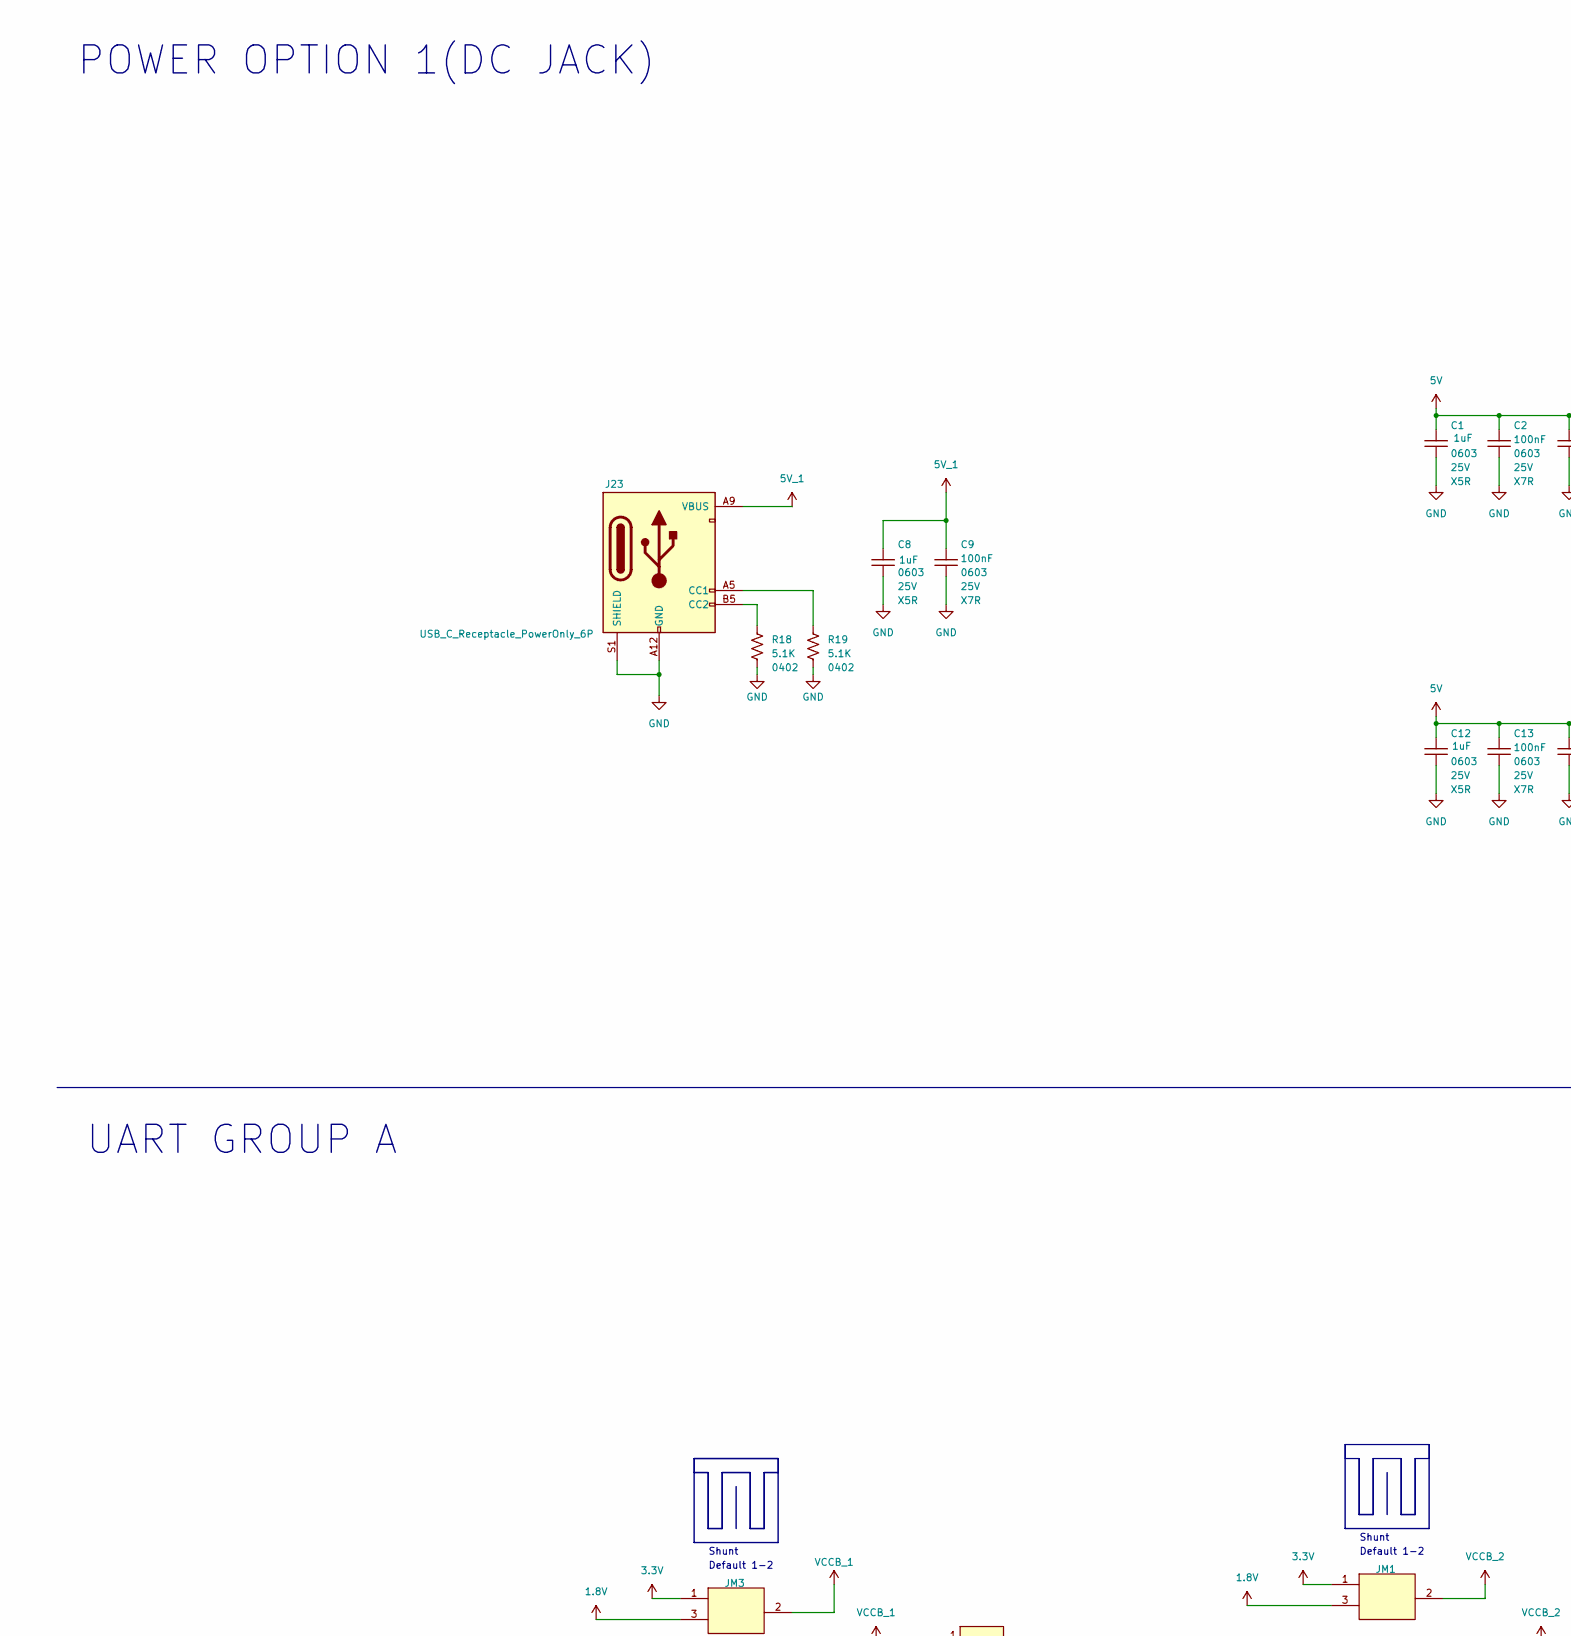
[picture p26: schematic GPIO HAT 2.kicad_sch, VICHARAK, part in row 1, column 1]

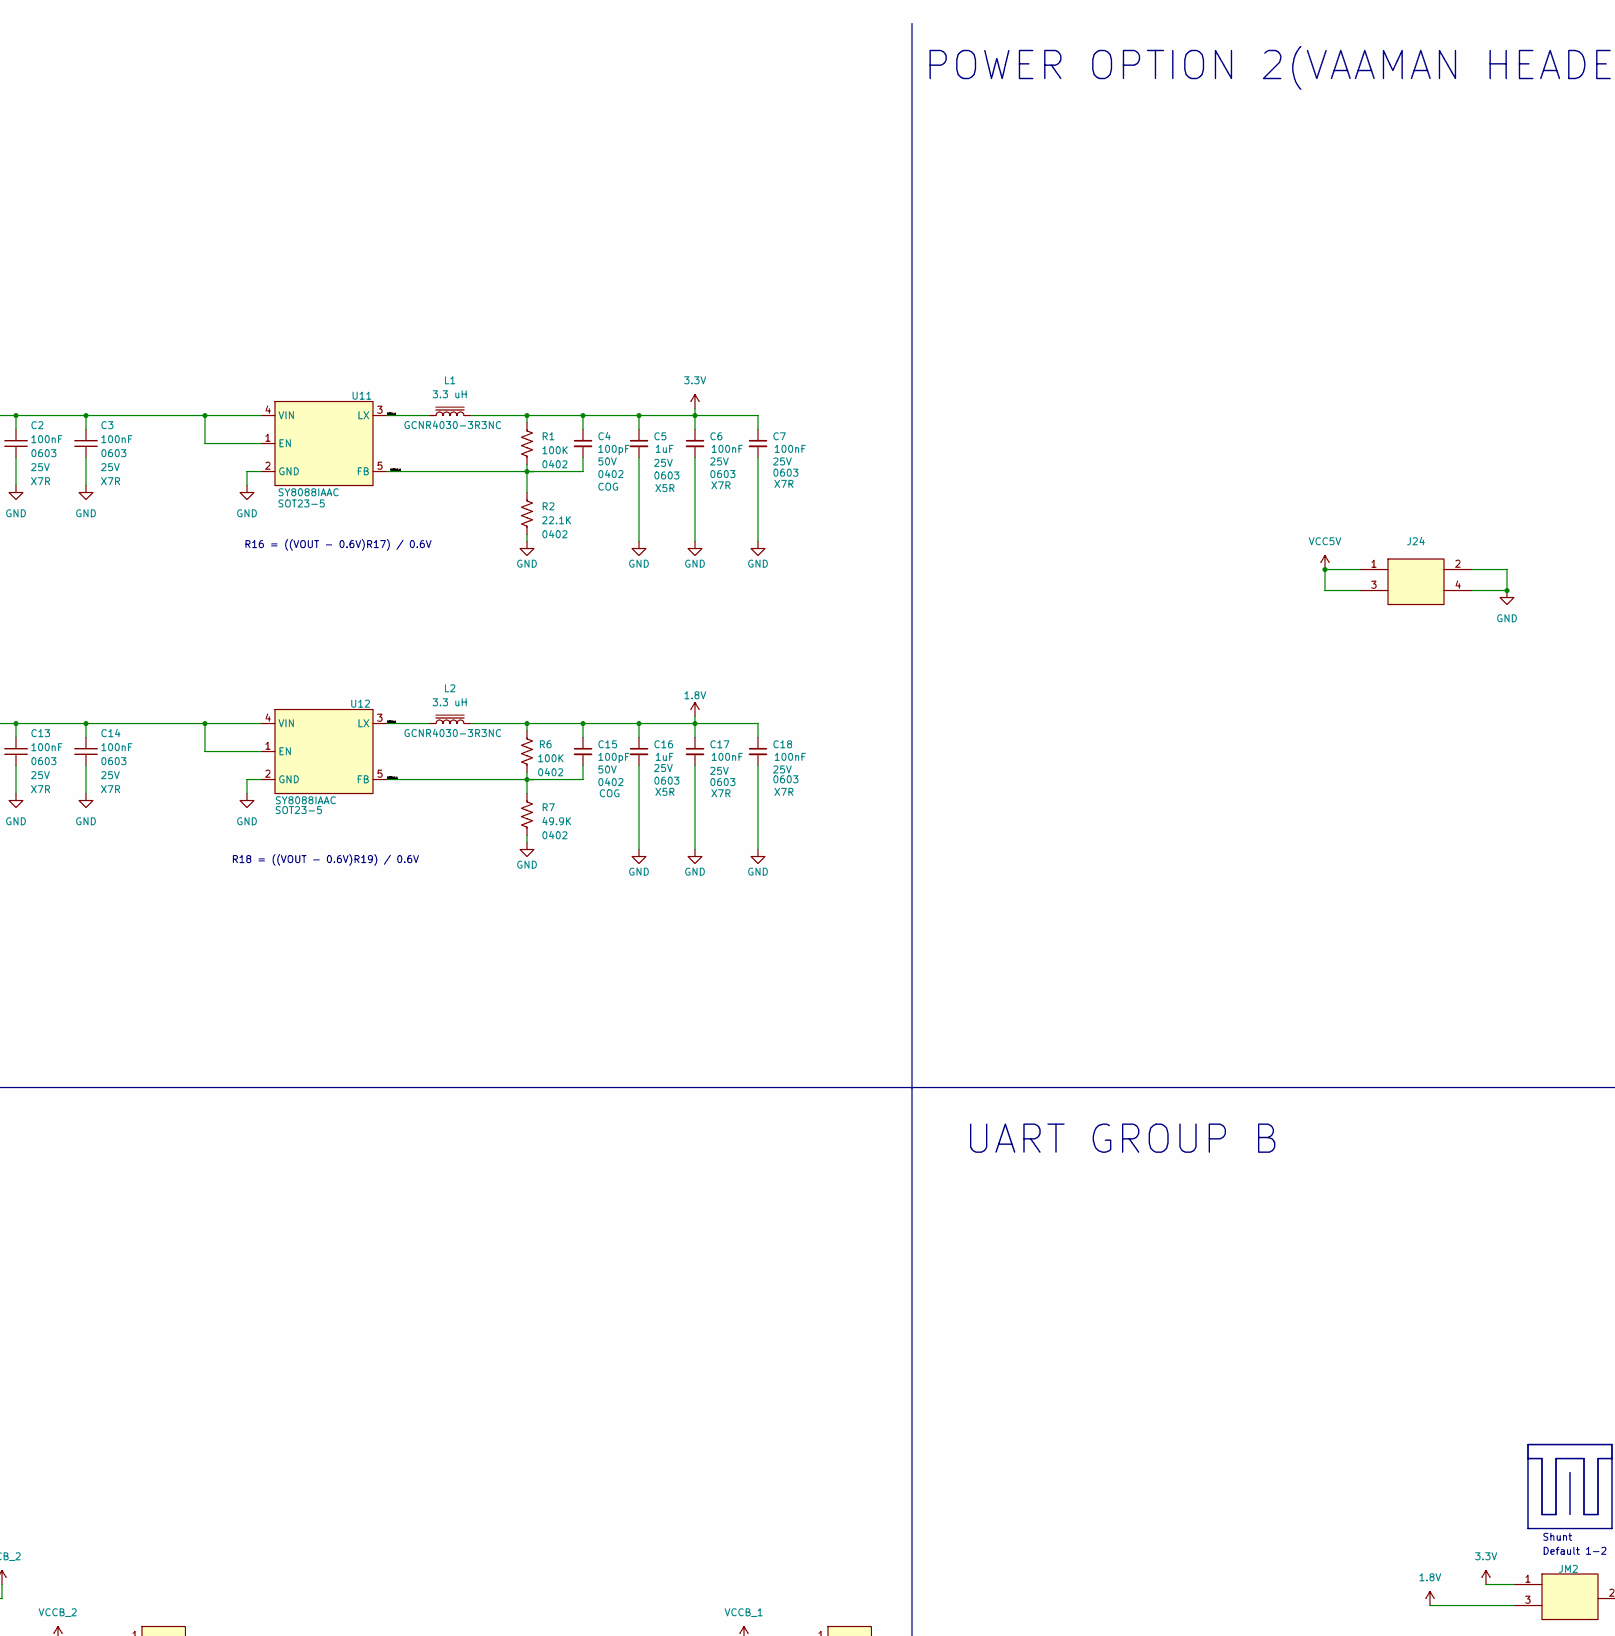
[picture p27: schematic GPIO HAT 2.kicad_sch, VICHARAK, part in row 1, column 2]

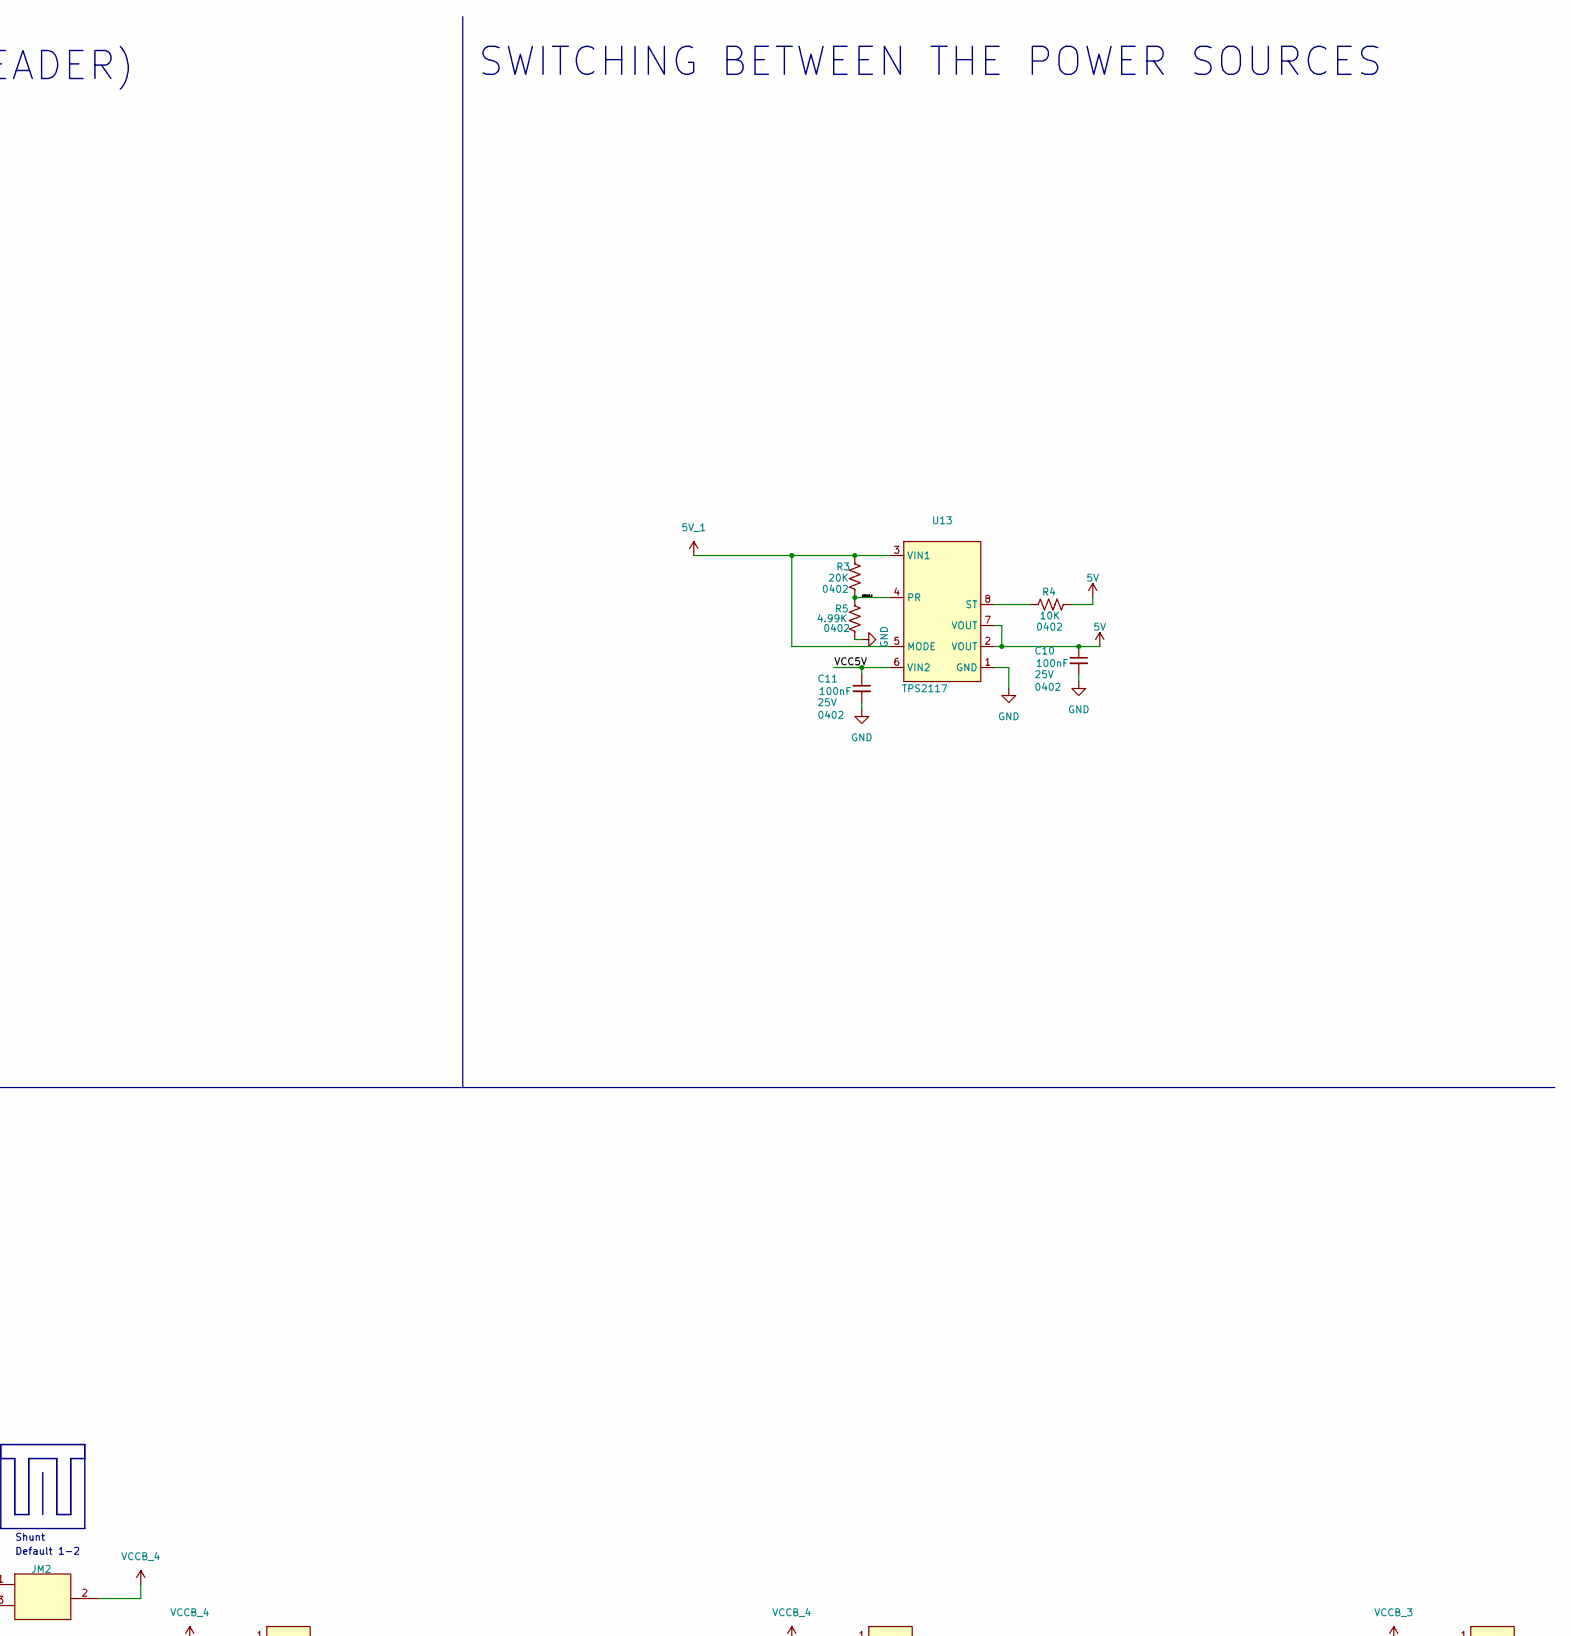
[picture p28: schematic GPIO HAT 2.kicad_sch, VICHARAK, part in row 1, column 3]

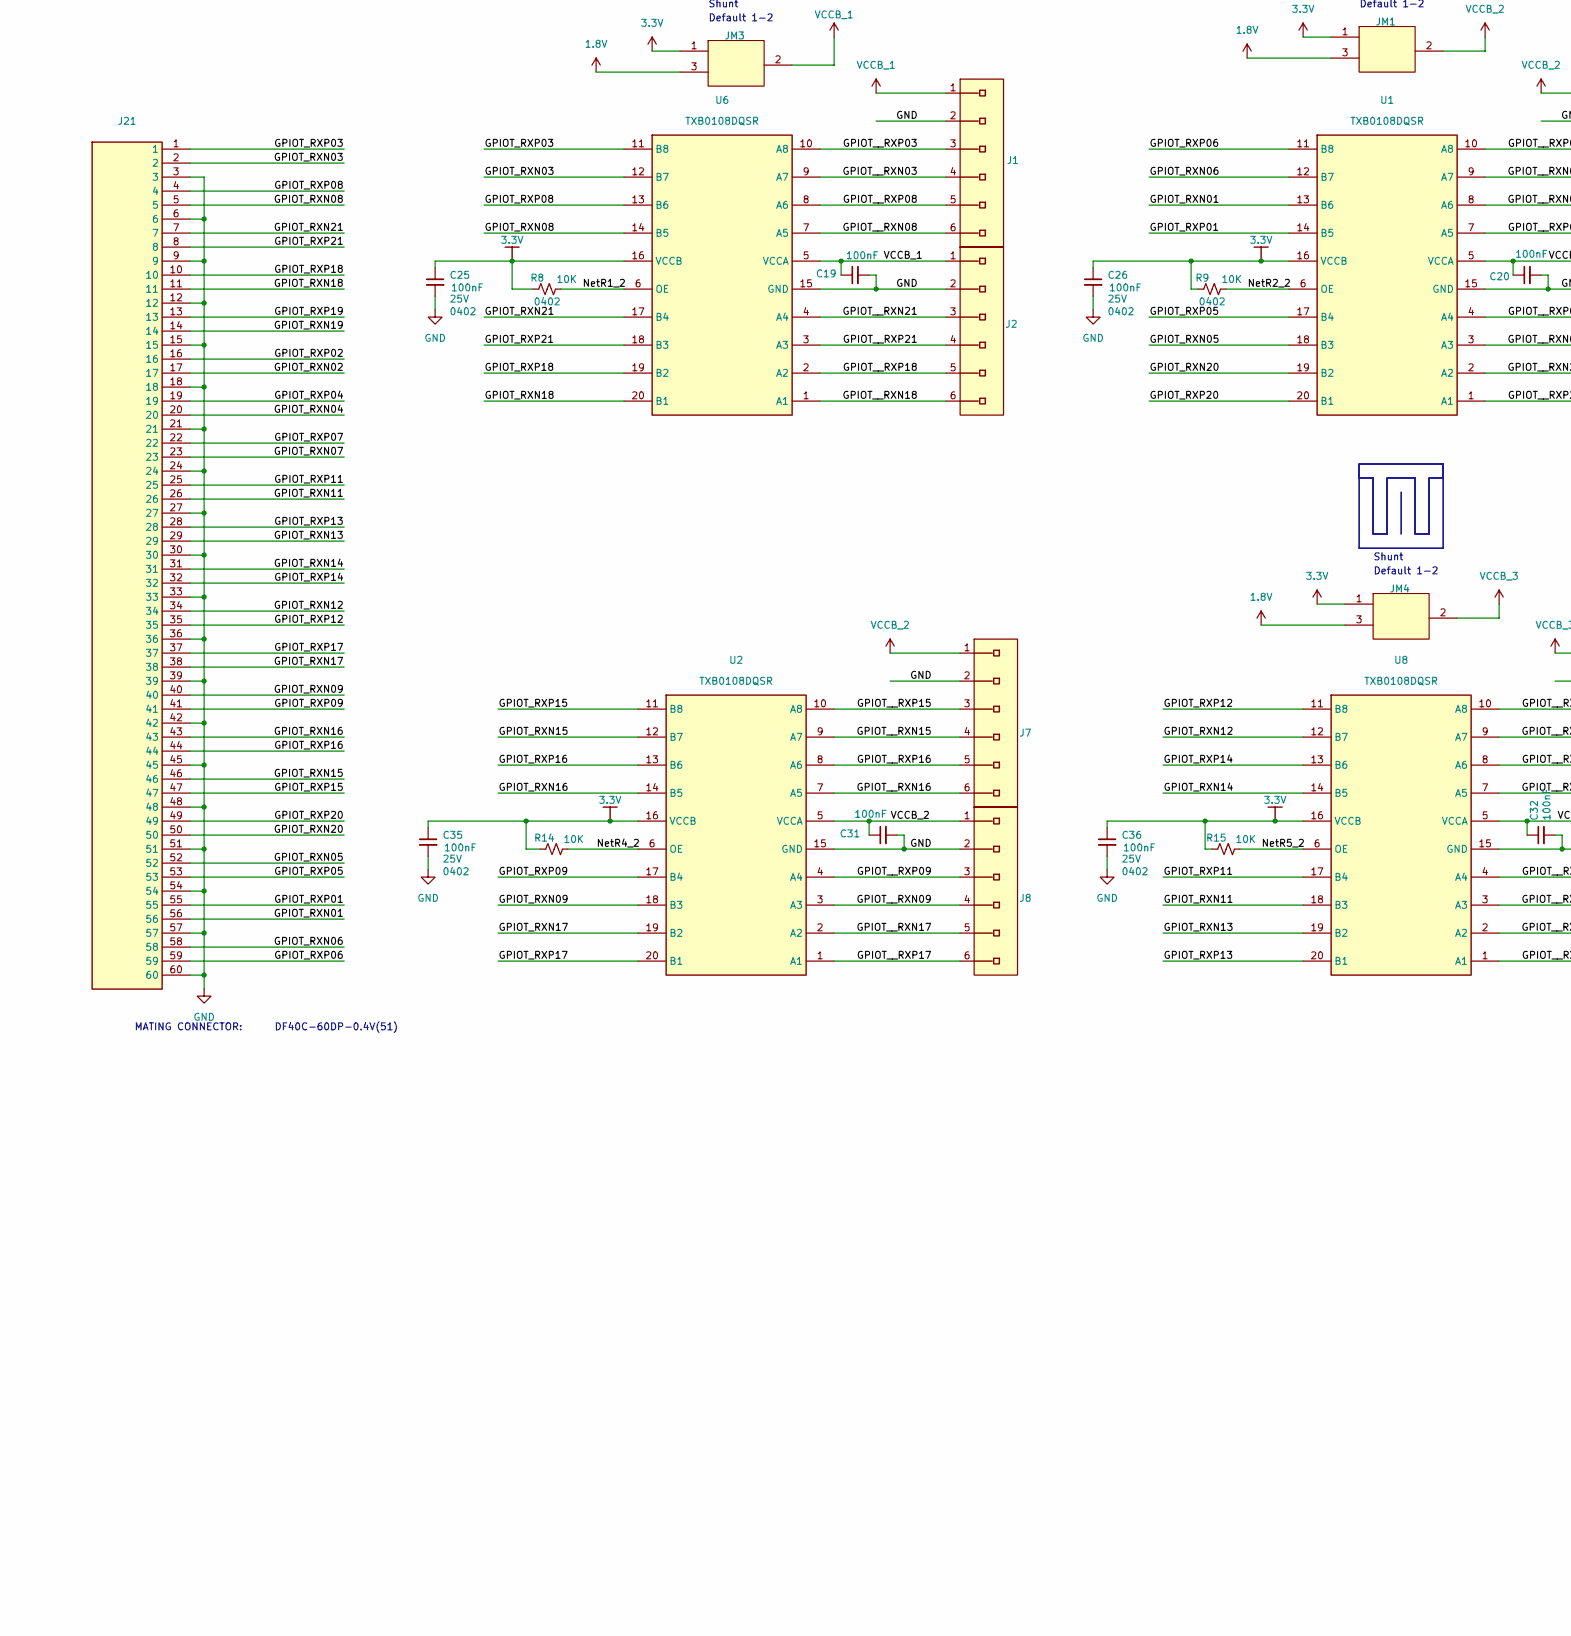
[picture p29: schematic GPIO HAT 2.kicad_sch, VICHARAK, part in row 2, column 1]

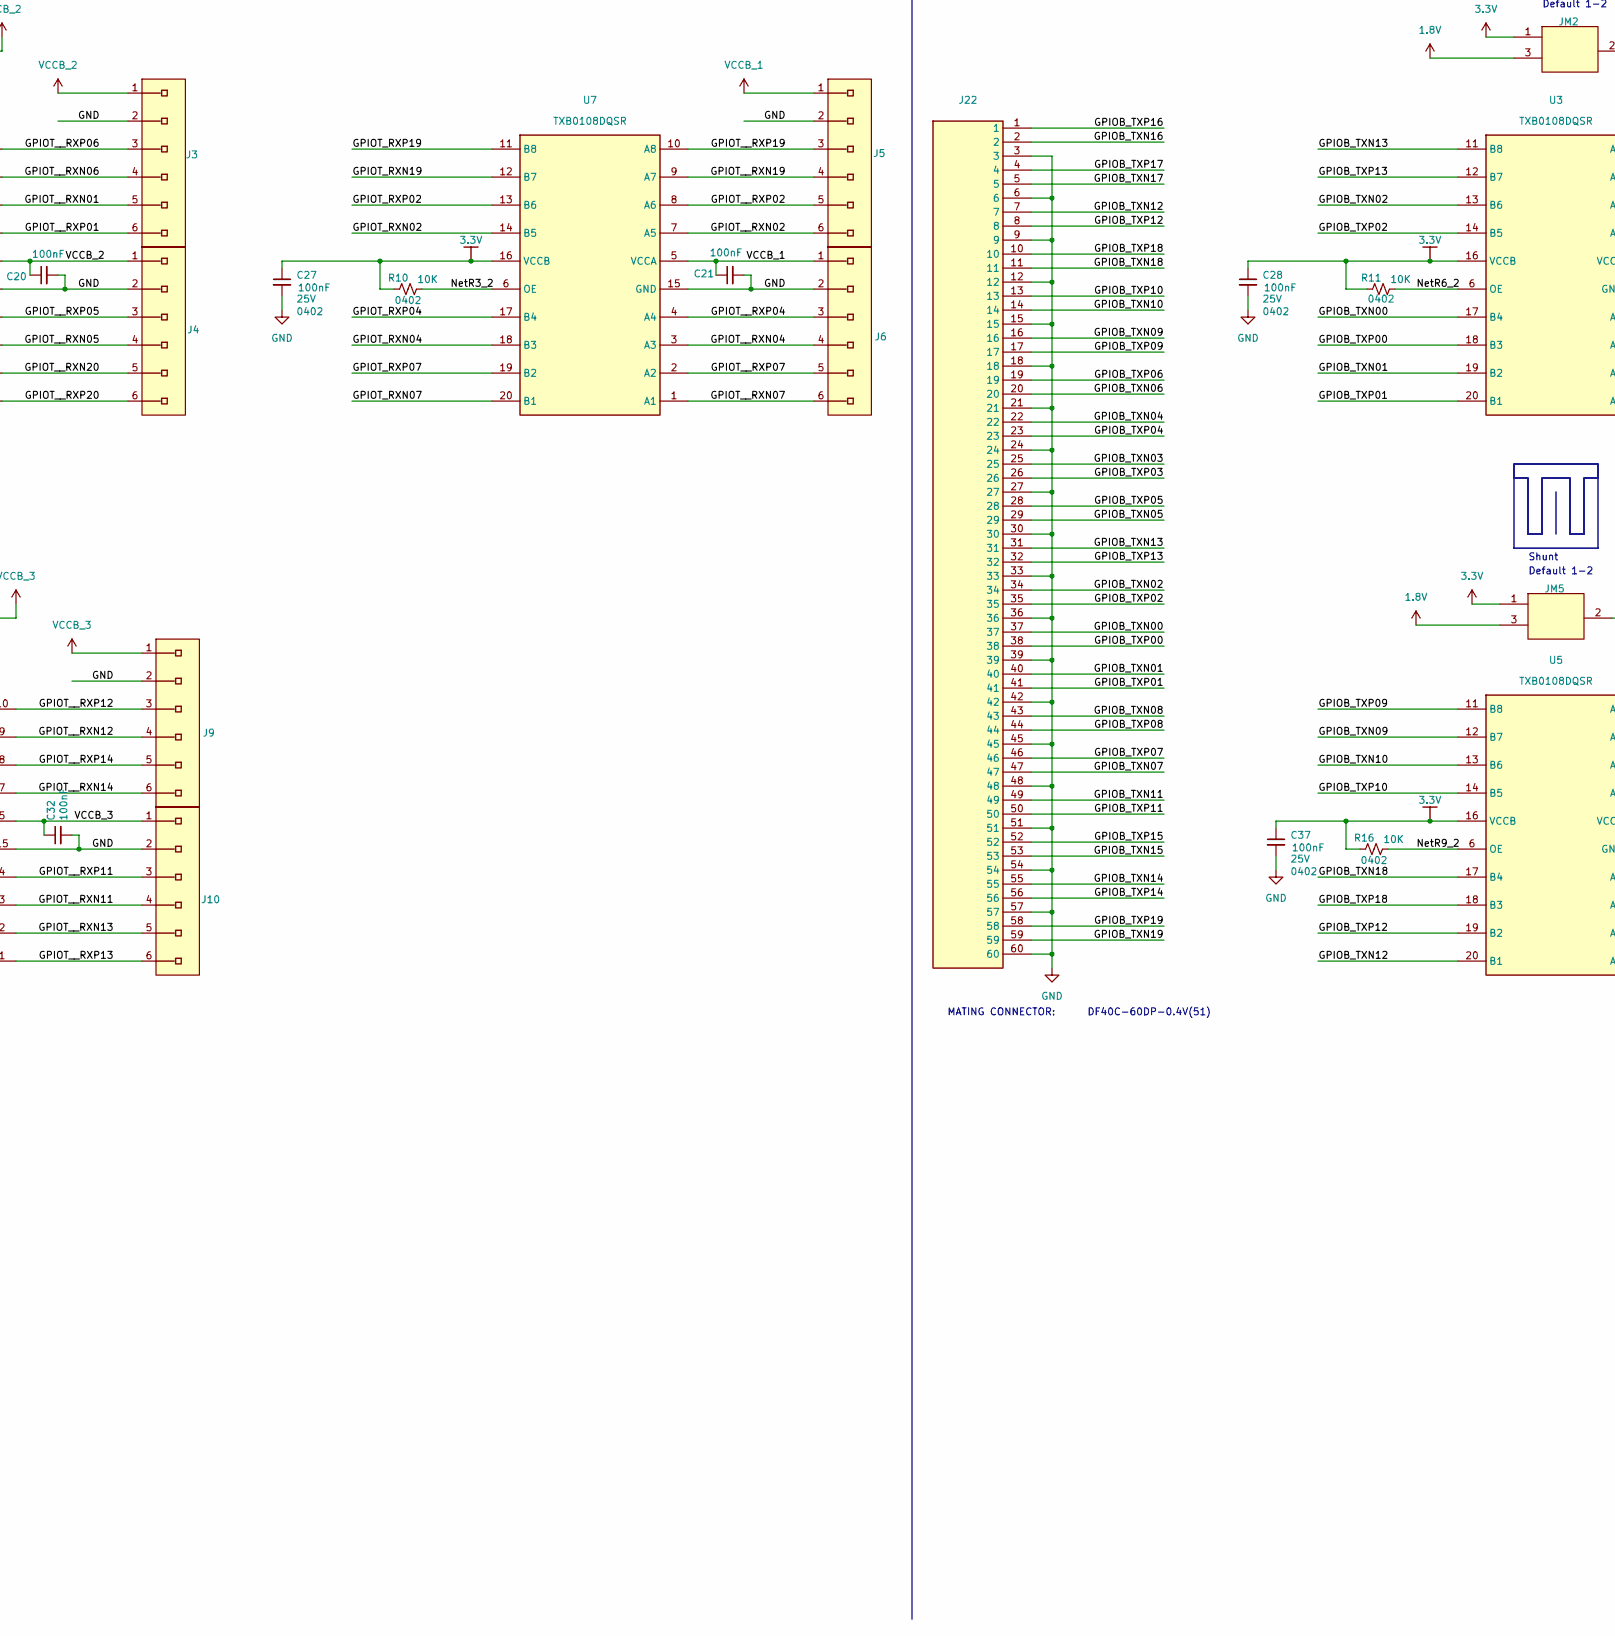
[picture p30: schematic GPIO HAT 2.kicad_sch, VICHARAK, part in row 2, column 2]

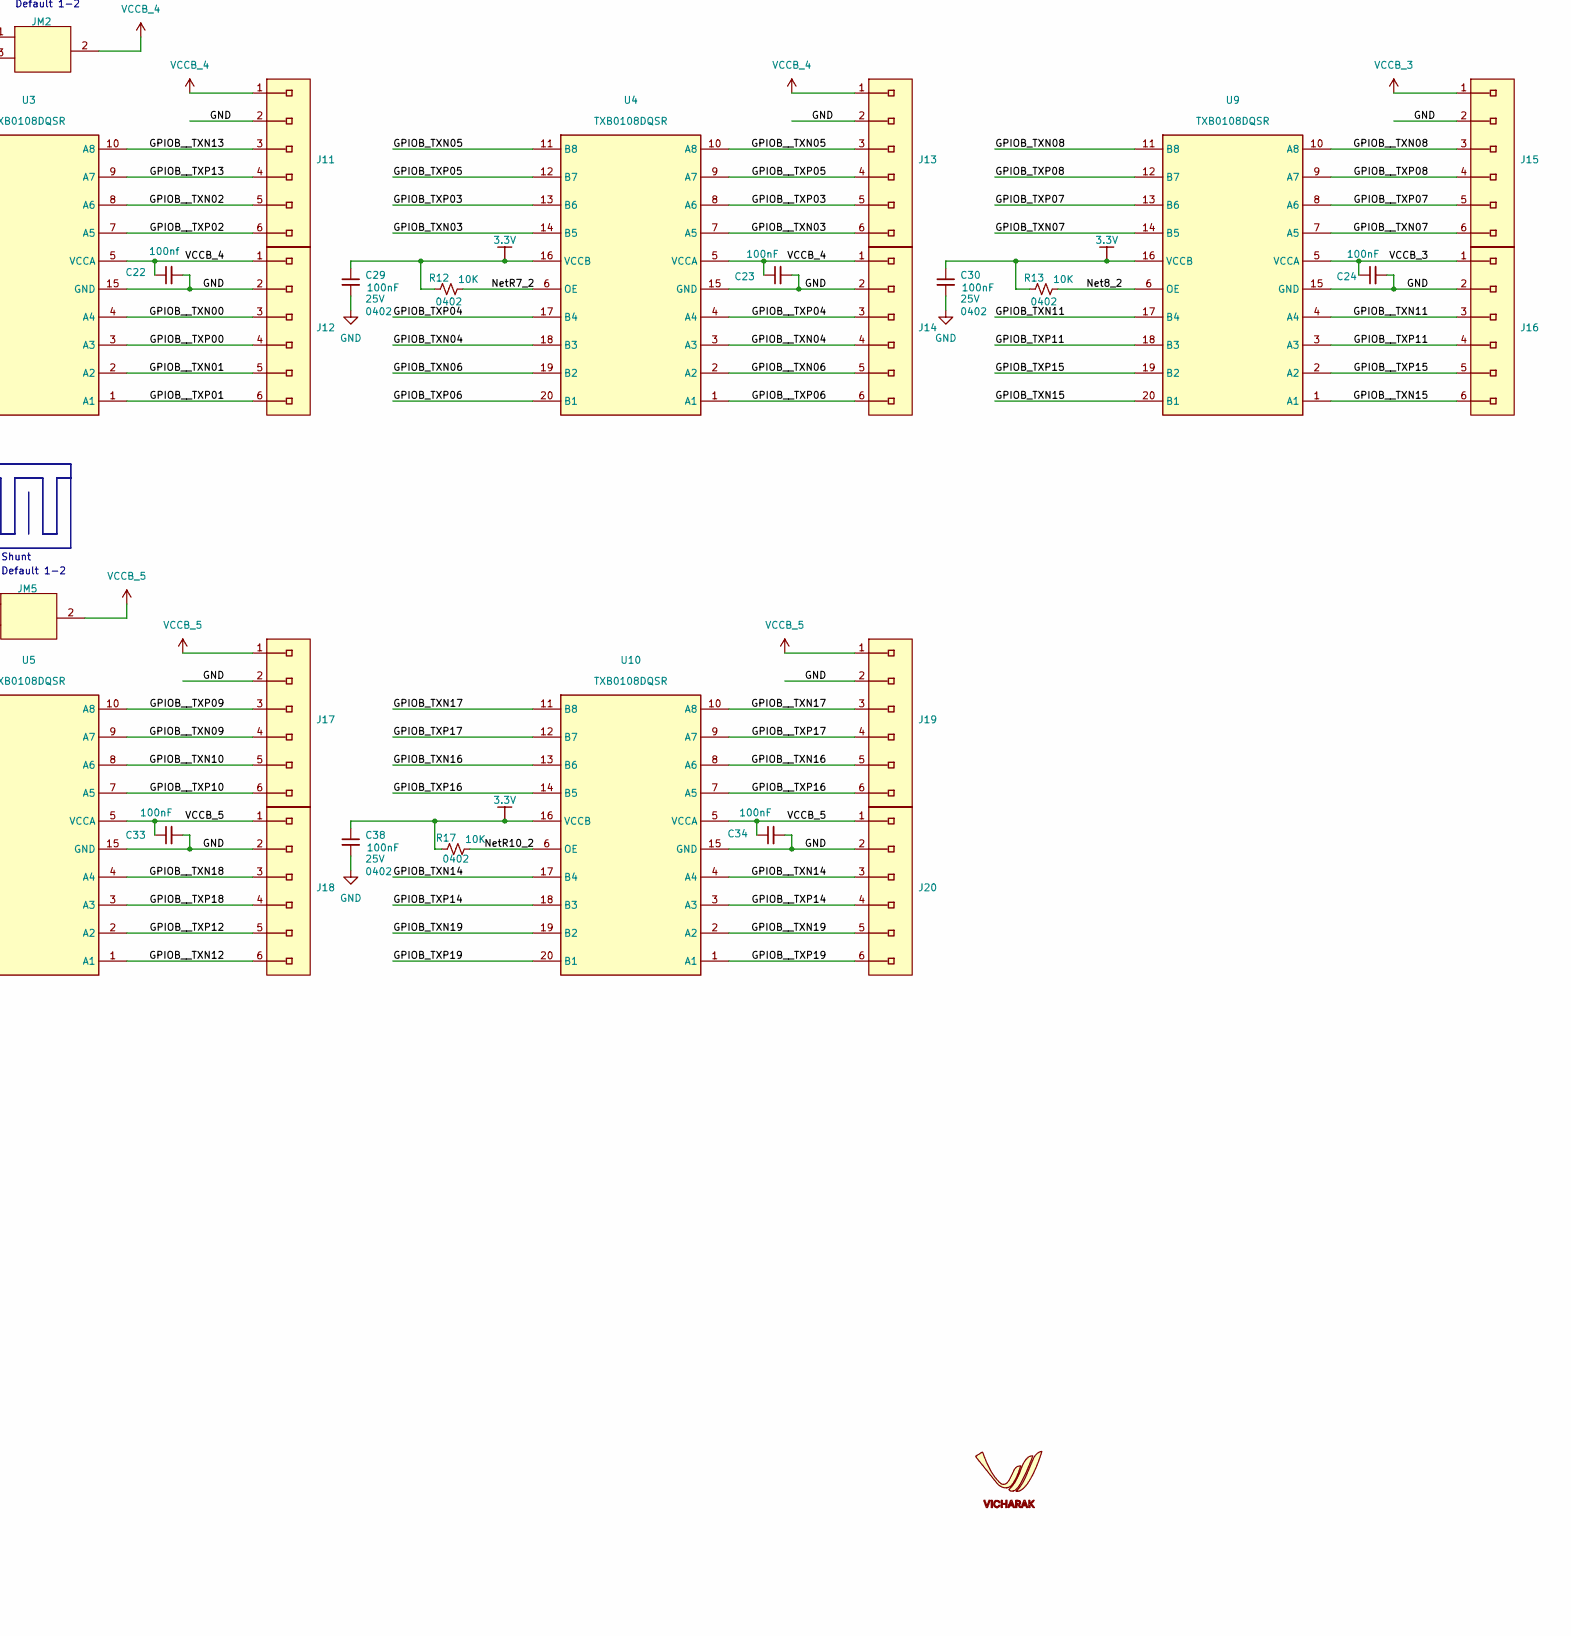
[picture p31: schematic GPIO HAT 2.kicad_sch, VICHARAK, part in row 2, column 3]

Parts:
C1, C5, C8, C12, C16: 1uF; 0603_Cap; VOLTAGE 25V
C2, C3, C6, C7, C9, C13, C14, C17, C18: 100nF; 0603_Cap; VOLTAGE 25V
C4, C15: 100pF; 0402_Cap; VOLTAGE 50V
C10, C11, C19, C20, C21, C23, C24, C25, C26, C27, C28, C29, C30, C31, C32, C33, C34, C35, C36, C37, C38: 100nF; 0402_Cap; VOLTAGE 25V
C22: 100nf; 0402_Cap; VOLTAGE 25V
J1, J2, J3, J4, J5, J6, J7, J8, J9, J10, J11, J12, J13, J14, J15, J16, J17, J18, J19, J20: .; 01x06 HEADER
J21, J22: LVDS; Mouser Part Number 798-DF40C60DS0.4V51
J23: USB_C_Receptacle_PowerOnly_6P; USB_C_Receptacle_GCT_USB4125-xx-x-0190_6P_TopMnt_Horizontal; Manufacturer Part Number U262-061N-4BVC10
J24: 02x02; 02X02 HEADER
JM1, JM2, JM3, JM4, JM5: PinHeader_1x03_P2.54mm_Vertical
L1, L2: 3.3 uH; GCNR4030-3R3NC; Manufacturer Part Number GCNR4030-3R3NC
R1, R6: 100K; 0402_Res
R2: 22.1K; 0402_Res
R3: 20K; 0402_Res
R4, R8, R9, R10, R11, R12, R13, R14, R15, R16, R17: 10K; 0402_Res
R5: 4.99K; 0402_Res
R7: 49.9K; 0402_Res
R18, R19: 5.1K; 0402_Res
U1, U2, U3, U4, U5, U6, U7, U8, U9, U10: Manufacturer Part Number TXB0108DQSR
U11, U12: SY8088IAAC; Manufacturer Part Number SY8088IAAC
U13: TPS2117

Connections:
1.8V: C15.1, C16.1, C17.1, C18.1, JM1.3, JM2.3, JM3.3, JM4.3, JM5.3, L2.2, R6.1
3.3V: C4.1, C5.1, C6.1, C7.1, C25.1, C26.1, C27.1, C28.1, C29.1, C30.1, C35.1, C36.1, C37.1, C38.1, JM1.1, JM2.1, JM3.1, JM4.1, JM5.1, L1.2, R1.1, R8.1, R9.1, R10.1, R11.1, R12.1, R13.1, R14.1, R15.1, R16.1, R17.1, U1.16 (VCCB), U2.16 (VCCB), U3.16 (VCCB), U4.16 (VCCB), U5.16 (VCCB), U6.16 (VCCB), U7.16 (VCCB), U8.16 (VCCB), U9.16 (VCCB), U10.16 (VCCB)
5V: C1.1, C2.1, C3.1, C10.1, C12.1, C13.1, C14.1, R4.2, U11.1 (EN), U11.4 (VIN), U12.1 (EN), U12.4 (VIN), U13.2 (VOUT), U13.7 (VOUT)
5V_1: C8.1, C9.1, J23.A9 (VBUS), R3.2, U13.3 (VIN1), U13.5 (MODE)
/GPIOB_TXN00: J22.37, U3.17 (B4)
/GPIOB_TXN01: J22.40, U3.19 (B2)
/GPIOB_TXN02: J22.34, U3.13 (B6)
/GPIOB_TXN03: J22.25, U4.14 (B5)
/GPIOB_TXN04: J22.22, U4.18 (B3)
/GPIOB_TXN05: J22.29, U4.11 (B8)
/GPIOB_TXN06: J22.20, U4.19 (B2)
/GPIOB_TXN07: J22.47, U9.14 (B5)
/GPIOB_TXN08: J22.43, U9.11 (B8)
/GPIOB_TXN09: J22.16, U5.12 (B7)
/GPIOB_TXN10: J22.14, U5.13 (B6)
/GPIOB_TXN11: J22.49, U9.17 (B4)
/GPIOB_TXN12: J22.7, U5.20 (B1)
/GPIOB_TXN13: J22.31, U3.11 (B8)
/GPIOB_TXN14: J22.55, U10.17 (B4)
/GPIOB_TXN15: J22.53, U9.20 (B1)
/GPIOB_TXN16: J22.2, U10.13 (B6)
/GPIOB_TXN17: J22.5, U10.11 (B8)
/GPIOB_TXN18: J22.11, U5.17 (B4)
/GPIOB_TXN19: J22.59, U10.19 (B2)
/GPIOB_TXP00: J22.38, U3.18 (B3)
/GPIOB_TXP01: J22.41, U3.20 (B1)
/GPIOB_TXP02: J22.35, U3.14 (B5)
/GPIOB_TXP03: J22.26, U4.13 (B6)
/GPIOB_TXP04: J22.23, U4.17 (B4)
/GPIOB_TXP05: J22.28, U4.12 (B7)
/GPIOB_TXP06: J22.19, U4.20 (B1)
/GPIOB_TXP07: J22.46, U9.13 (B6)
/GPIOB_TXP08: J22.44, U9.12 (B7)
/GPIOB_TXP09: J22.17, U5.11 (B8)
/GPIOB_TXP10: J22.13, U5.14 (B5)
/GPIOB_TXP11: J22.50, U9.18 (B3)
/GPIOB_TXP12: J22.8, U5.19 (B2)
/GPIOB_TXP13: J22.32, U3.12 (B7)
/GPIOB_TXP14: J22.56, U10.18 (B3)
/GPIOB_TXP15: J22.52, U9.19 (B2)
/GPIOB_TXP16: J22.1, U10.14 (B5)
/GPIOB_TXP17: J22.4, U10.12 (B7)
/GPIOB_TXP18: J22.10, U5.18 (B3)
/GPIOB_TXP19: J22.58, U10.20 (B1)
/GPIOB__TXN00: J12.3, U3.4 (A4)
/GPIOB__TXN01: J12.5 (4), U3.2 (A2)
/GPIOB__TXN02: J11.5 (4), U3.8 (A6)
/GPIOB__TXN03: J13.6, U4.7 (A5)
/GPIOB__TXN04: J14.4, U4.3 (A3)
/GPIOB__TXN05: J13.3, U4.10 (A8)
/GPIOB__TXN06: J14.5 (4), U4.2 (A2)
/GPIOB__TXN07: J15.6, U9.7 (A5)
/GPIOB__TXN08: J15.3, U9.10 (A8)
/GPIOB__TXN09: J17.4, U5.9 (A7)
/GPIOB__TXN10: J17.5 (4), U5.8 (A6)
/GPIOB__TXN11: J16.3, U9.4 (A4)
/GPIOB__TXN12: J18.6, U5.1 (A1)
/GPIOB__TXN13: J11.3, U3.10 (A8)
/GPIOB__TXN14: J20.3, U10.4 (A4)
/GPIOB__TXN15: J16.6, U9.1 (A1)
/GPIOB__TXN16: J19.5 (4), U10.8 (A6)
/GPIOB__TXN17: J19.3, U10.10 (A8)
/GPIOB__TXN18: J18.3, U5.4 (A4)
/GPIOB__TXN19: J20.5 (4), U10.2 (A2)
/GPIOB__TXP00: J12.4, U3.3 (A3)
/GPIOB__TXP01: J12.6, U3.1 (A1)
/GPIOB__TXP02: J11.6, U3.7 (A5)
/GPIOB__TXP03: J13.5 (4), U4.8 (A6)
/GPIOB__TXP04: J14.3, U4.4 (A4)
/GPIOB__TXP05: J13.4, U4.9 (A7)
/GPIOB__TXP06: J14.6, U4.1 (A1)
/GPIOB__TXP07: J15.5 (4), U9.8 (A6)
/GPIOB__TXP08: J15.4, U9.9 (A7)
/GPIOB__TXP09: J17.3, U5.10 (A8)
/GPIOB__TXP10: J17.6, U5.7 (A5)
/GPIOB__TXP11: J16.4, U9.3 (A3)
/GPIOB__TXP12: J18.5 (4), U5.2 (A2)
/GPIOB__TXP13: J11.4, U3.9 (A7)
/GPIOB__TXP14: J20.4, U10.3 (A3)
/GPIOB__TXP15: J16.5 (4), U9.2 (A2)
/GPIOB__TXP16: J19.6, U10.7 (A5)
/GPIOB__TXP17: J19.4, U10.9 (A7)
/GPIOB__TXP18: J18.4, U5.3 (A3)
/GPIOB__TXP19: J20.6, U10.1 (A1)
/GPIOT_RXN01: J21.56, U1.13 (B6)
/GPIOT_RXN02: J21.17, U7.14 (B5)
/GPIOT_RXN03: J21.2, U6.12 (B7)
/GPIOT_RXN04: J21.20, U7.18 (B3)
/GPIOT_RXN05: J21.52, U1.18 (B3)
/GPIOT_RXN06: J21.58, U1.12 (B7)
/GPIOT_RXN07: J21.23, U7.20 (B1)
/GPIOT_RXN08: J21.5, U6.14 (B5)
/GPIOT_RXN09: J21.40, U2.18 (B3)
/GPIOT_RXN11: J21.26, U8.18 (B3)
/GPIOT_RXN12: J21.34, U8.12 (B7)
/GPIOT_RXN13: J21.29, U8.19 (B2)
/GPIOT_RXN14: J21.31, U8.14 (B5)
/GPIOT_RXN15: J21.46, U2.12 (B7)
/GPIOT_RXN16: J21.43, U2.14 (B5)
/GPIOT_RXN17: J21.38, U2.19 (B2)
/GPIOT_RXN18: J21.11, U6.20 (B1)
/GPIOT_RXN19: J21.14, U7.12 (B7)
/GPIOT_RXN20: J21.50, U1.19 (B2)
/GPIOT_RXN21: J21.7, U6.17 (B4)
/GPIOT_RXP01: J21.55, U1.14 (B5)
/GPIOT_RXP02: J21.16, U7.13 (B6)
/GPIOT_RXP03: J21.1, U6.11 (B8)
/GPIOT_RXP04: J21.19, U7.17 (B4)
/GPIOT_RXP05: J21.53, U1.17 (B4)
/GPIOT_RXP06: J21.59, U1.11 (B8)
/GPIOT_RXP07: J21.22, U7.19 (B2)
/GPIOT_RXP08: J21.4, U6.13 (B6)
/GPIOT_RXP09: J21.41, U2.17 (B4)
/GPIOT_RXP11: J21.25, U8.17 (B4)
/GPIOT_RXP12: J21.35, U8.11 (B8)
/GPIOT_RXP13: J21.28, U8.20 (B1)
/GPIOT_RXP14: J21.32, U8.13 (B6)
/GPIOT_RXP15: J21.47, U2.11 (B8)
/GPIOT_RXP16: J21.44, U2.13 (B6)
/GPIOT_RXP17: J21.37, U2.20 (B1)
/GPIOT_RXP18: J21.10, U6.19 (B2)
/GPIOT_RXP19: J21.13, U7.11 (B8)
/GPIOT_RXP20: J21.49, U1.20 (B1)
/GPIOT_RXP21: J21.8, U6.18 (B3)
/GPIOT__RXN01: J3.5 (4), U1.8 (A6)
/GPIOT__RXN02: J5.6, U7.7 (A5)
/GPIOT__RXN03: J1.4, U6.9 (A7)
/GPIOT__RXN04: J6.4, U7.3 (A3)
/GPIOT__RXN05: J4.4, U1.3 (A3)
/GPIOT__RXN06: J3.4, U1.9 (A7)
/GPIOT__RXN07: J6.6, U7.1 (A1)
/GPIOT__RXN08: J1.6, U6.7 (A5)
/GPIOT__RXN09: J8.4, U2.3 (A3)
/GPIOT__RXN11: J10.4, U8.3 (A3)
/GPIOT__RXN12: J9.4, U8.9 (A7)
/GPIOT__RXN13: J10.5 (4), U8.2 (A2)
/GPIOT__RXN14: J9.6, U8.7 (A5)
/GPIOT__RXN15: J7.4, U2.9 (A7)
/GPIOT__RXN16: J7.6, U2.7 (A5)
/GPIOT__RXN17: J8.5 (4), U2.2 (A2)
/GPIOT__RXN18: J2.6, U6.1 (A1)
/GPIOT__RXN19: J5.4, U7.9 (A7)
/GPIOT__RXN20: J4.5 (4), U1.2 (A2)
/GPIOT__RXN21: J2.3, U6.4 (A4)
/GPIOT__RXP01: J3.6, U1.7 (A5)
/GPIOT__RXP02: J5.5 (4), U7.8 (A6)
/GPIOT__RXP03: J1.3, U6.10 (A8)
/GPIOT__RXP04: J6.3, U7.4 (A4)
/GPIOT__RXP05: J4.3, U1.4 (A4)
/GPIOT__RXP06: J3.3, U1.10 (A8)
/GPIOT__RXP07: J6.5 (4), U7.2 (A2)
/GPIOT__RXP08: J1.5 (4), U6.8 (A6)
/GPIOT__RXP09: J8.3, U2.4 (A4)
/GPIOT__RXP11: J10.3, U8.4 (A4)
/GPIOT__RXP12: J9.3, U8.10 (A8)
/GPIOT__RXP13: J10.6, U8.1 (A1)
/GPIOT__RXP14: J9.5 (4), U8.8 (A6)
/GPIOT__RXP15: J7.3, U2.10 (A8)
/GPIOT__RXP16: J7.5 (4), U2.8 (A6)
/GPIOT__RXP17: J8.6, U2.1 (A1)
/GPIOT__RXP18: J2.5 (4), U6.2 (A2)
/GPIOT__RXP19: J5.3, U7.10 (A8)
/GPIOT__RXP20: J4.6, U1.1 (A1)
/GPIOT__RXP21: J2.4, U6.3 (A3)
/NETL1_1: L1.1, U11.3 (LX)
/NETL3_1: L2.1, U12.3 (LX)
/NETR16_1: C4.2, R1.2, R2.1, U11.5 (FB)
/NETR18_1: C15.2, R6.2, R7.1, U12.5 (FB)
/NETR20_2: R3.1, R5.2, U13.4 (PR)
/Net8_2: R13.2, U9.6 (OE)
/NetR1_2: R8.2, U6.6 (OE)
/NetR2_2: R9.2, U1.6 (OE)
/NetR3_2: R10.2, U7.6 (OE)
/NetR4_2: R14.2, U2.6 (OE)
/NetR5_2: R15.2, U8.6 (OE)
/NetR6_2: R11.2, U3.6 (OE)
/NetR7_2: R12.2, U4.6 (OE)
/NetR9_2: R16.2, U5.6 (OE)
/NetR10_2: R17.2, U10.6 (OE)
GND: C1.2, C2.2, C3.2, C5.2, C6.2, C7.2, C8.2, C9.2, C10.2, C11.2, C12.2, C13.2, C14.2, C16.2, C17.2, C18.2, C19.2, C20.2, C21.2, C22.2, C23.2, C24.2, C25.2, C26.2, C27.2, C28.2, C29.2, C30.2, C31.2, C32.2, C33.2, C34.2, C35.2, C36.2, C37.2, C38.2, J1.2, J2.2, J3.2, J4.2, J5.2, J6.2, J7.2, J8.2, J9.2, J10.2, J11.2, J12.2, J13.2, J14.2, J15.2, J16.2, J17.2, J18.2, J19.2, J20.2, J21.3, J21.6, J21.9, J21.12, J21.15, J21.18, J21.21, J21.24, J21.27, J21.30, J21.33, J21.36, J21.39, J21.42, J21.45, J21.48, J21.51, J21.54, J21.57, J21.60, J22.3, J22.6, J22.9, J22.12, J22.15, J22.18, J22.21, J22.24, J22.27, J22.30, J22.33, J22.36, J22.39, J22.42, J22.45, J22.48, J22.51, J22.54, J22.57, J22.60, J23.A12 (GND), J23.B12 (GND), J23.S1 (SHIELD), J24.2, J24.4 (3), R2.2, R5.1, R7.2, R18.2, R19.2, U1.15 (GND), U2.15 (GND), U3.15 (GND), U4.15 (GND), U5.15 (GND), U6.15 (GND), U7.15 (GND), U8.15 (GND), U9.15 (GND), U10.15 (GND), U11.2 (GND), U12.2 (GND), U13.1 (GND)
unnamed: J23.A5 (CC1), R19.1
unnamed: J23.B5 (CC2), R18.1
unnamed: R4.1, U13.8 (ST)
VCC5V: C11.1, J24.1, J24.3, U13.6 (VIN2)
VCCB_1: C19.1, C21.1, J1.1, J2.1, J5.1, J6.1, JM3.2, U6.5 (VCCA), U7.5 (VCCA)
VCCB_2: C20.1, C31.1, J3.1, J4.1, J7.1, J8.1, JM1.2, U1.5 (VCCA), U2.5 (VCCA)
VCCB_3: C24.1, C32.1, J9.1, J10.1, J15.1, J16.1, JM4.2, U8.5 (VCCA), U9.5 (VCCA)
VCCB_4: C22.1, C23.1, J11.1, J12.1, J13.1, J14.1, JM2.2, U3.5 (VCCA), U4.5 (VCCA)
VCCB_5: C33.1, C34.1, J17.1, J18.1, J19.1, J20.1, JM5.2, U5.5 (VCCA), U10.5 (VCCA)

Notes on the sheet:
DF40C-60DP-0.4V(51)
UART GROUP B
POWER OPTION 1(DC JACK)
MATING CONNECTOR:
Shunt
Default 1-2
R18 = ((VOUT - 0.6V)R19) / 0.6V
POWER OPTION 2(VAAMAN HEADER)
R16 = ((VOUT - 0.6V)R17) / 0.6V
UART GROUP A
SWITCHING BETWEEN THE POWER SOURCES

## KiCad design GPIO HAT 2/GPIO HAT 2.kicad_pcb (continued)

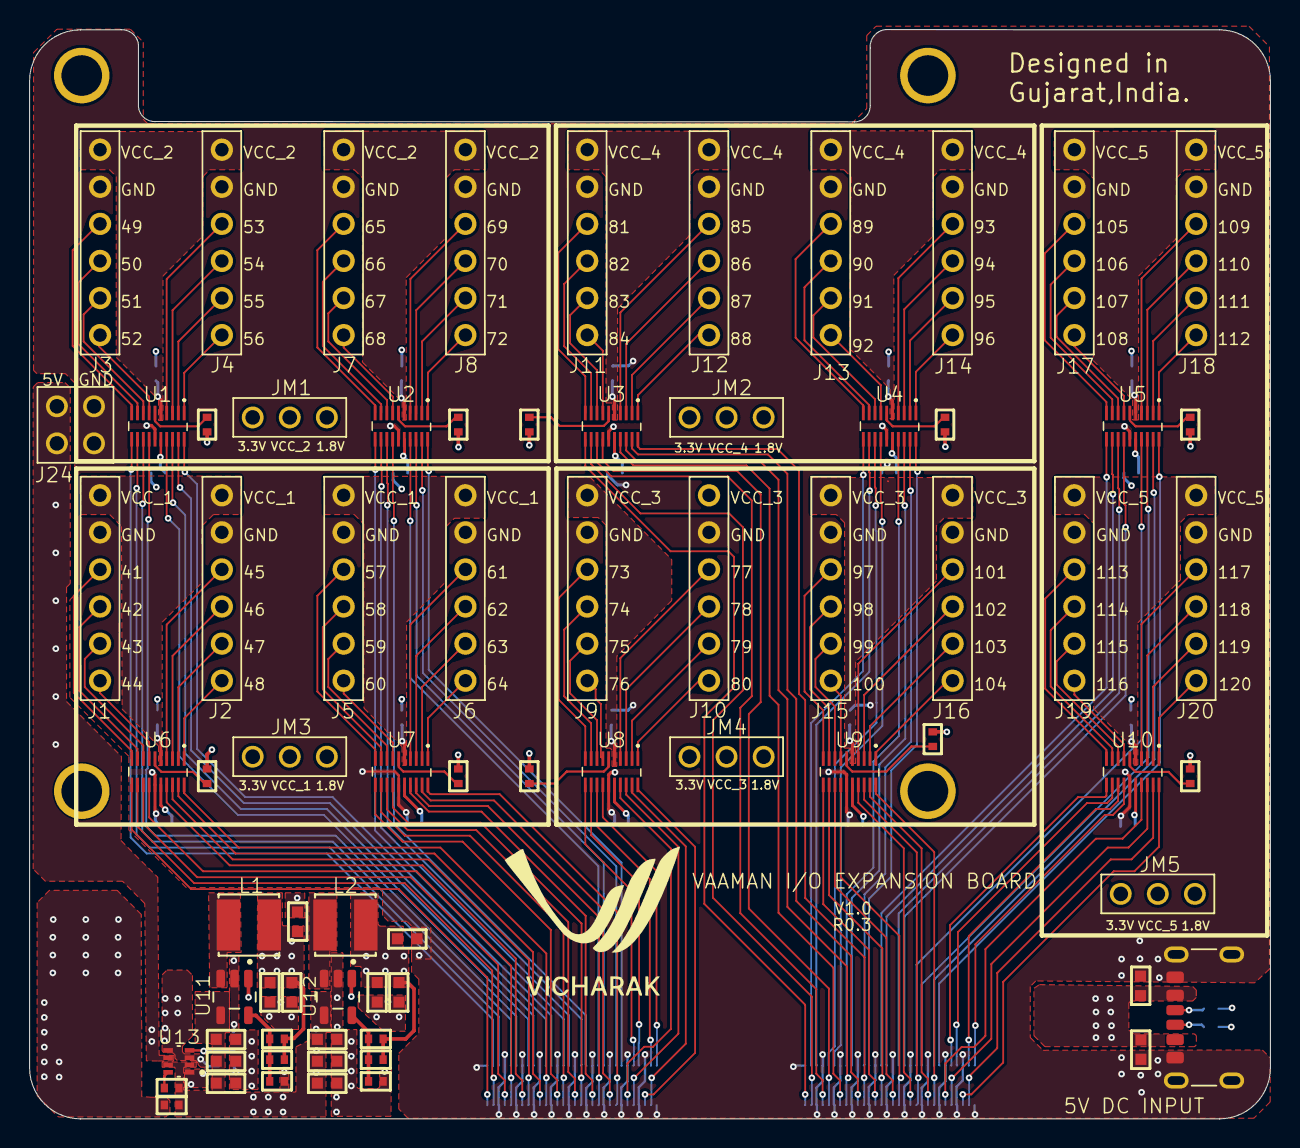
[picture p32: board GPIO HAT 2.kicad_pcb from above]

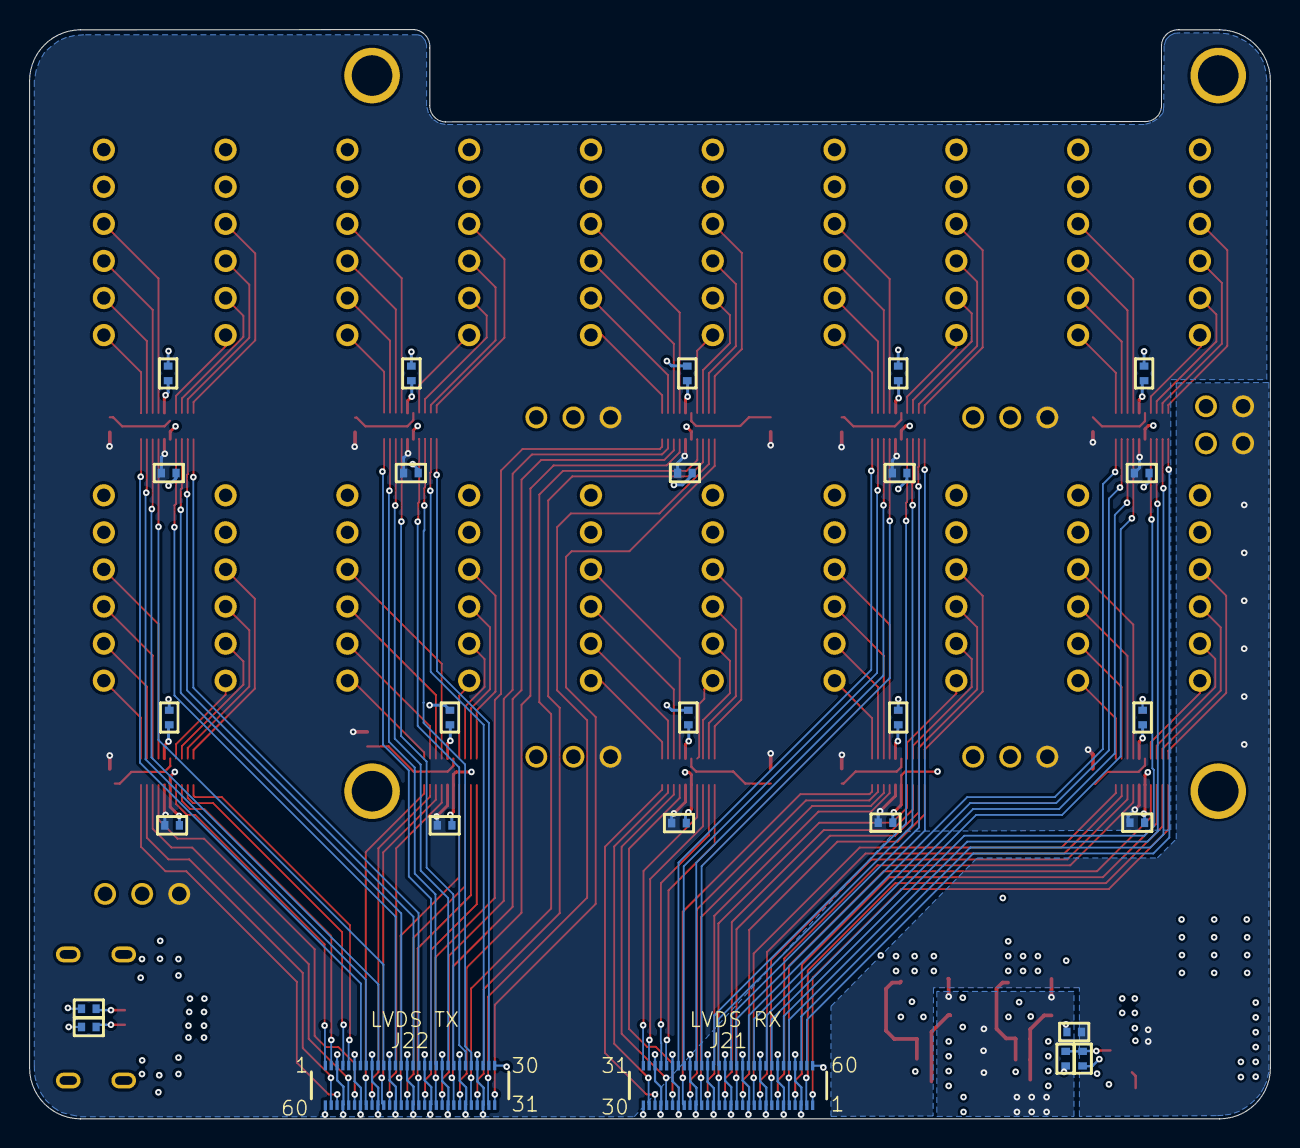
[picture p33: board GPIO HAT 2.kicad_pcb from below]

Board: 4 copper layers, 85.0 x 74.6 mm, 101 parts (27 on the bottom side), 189 nets.

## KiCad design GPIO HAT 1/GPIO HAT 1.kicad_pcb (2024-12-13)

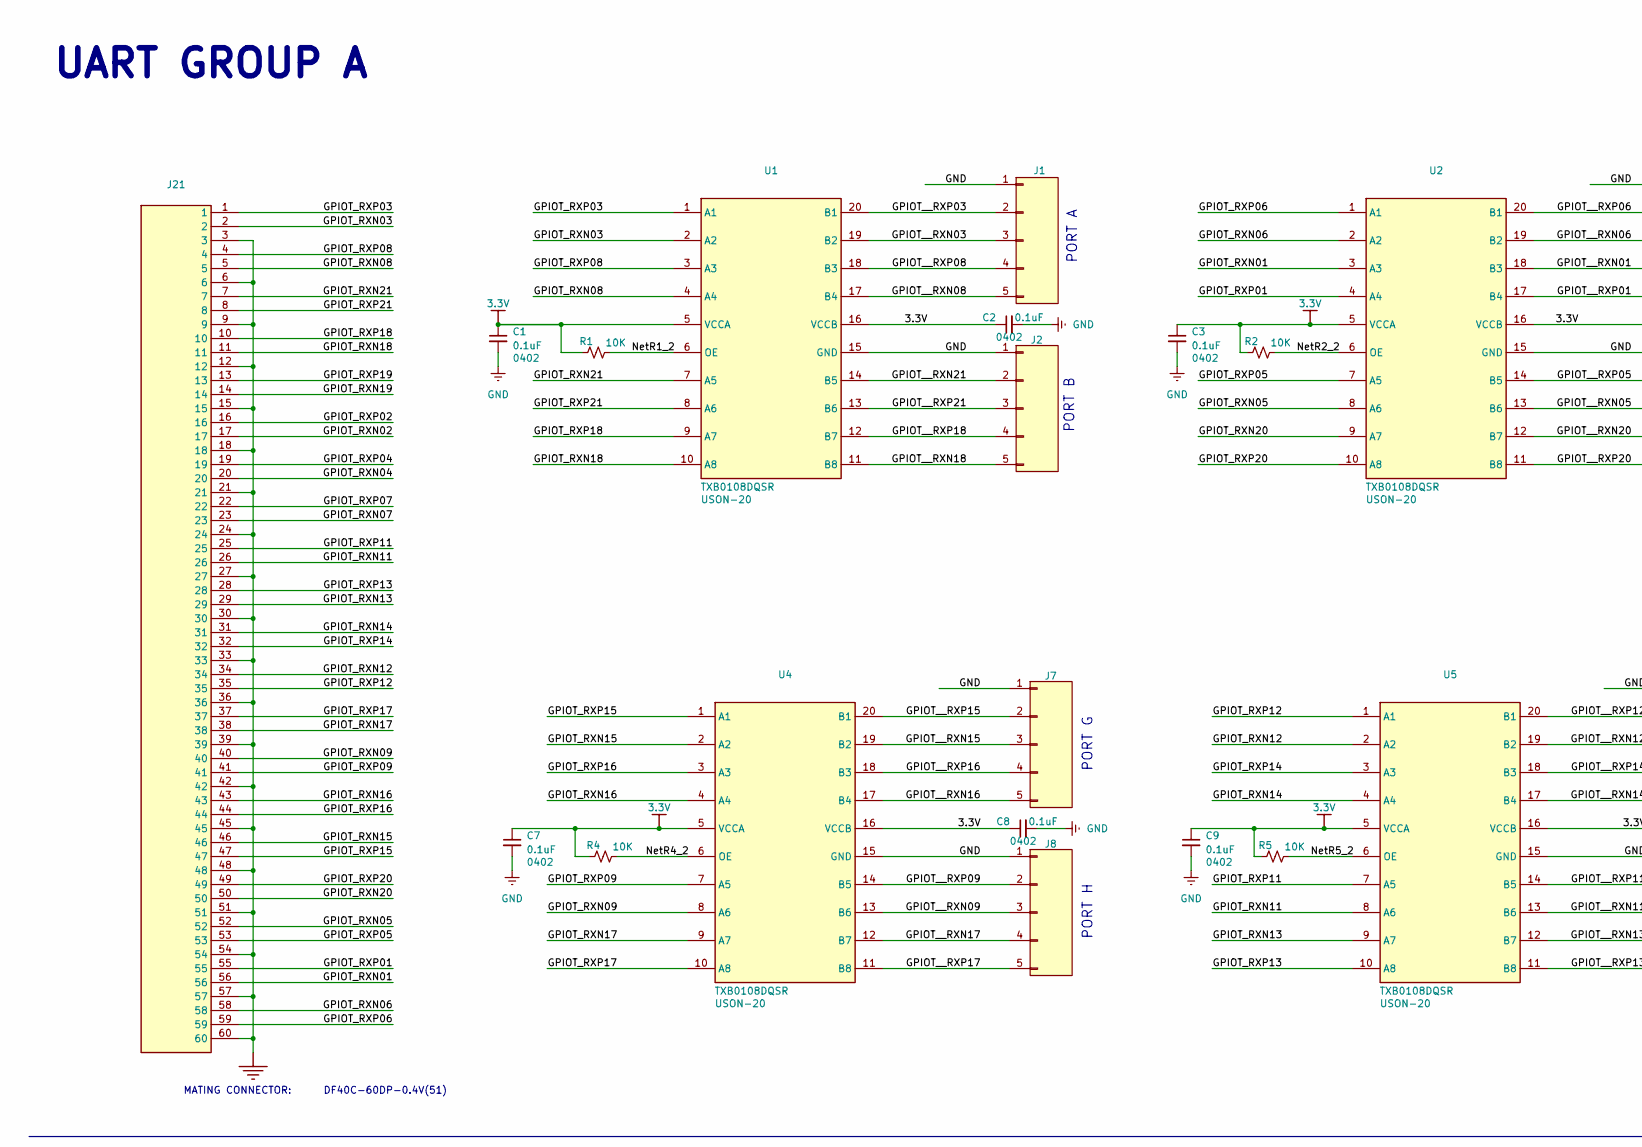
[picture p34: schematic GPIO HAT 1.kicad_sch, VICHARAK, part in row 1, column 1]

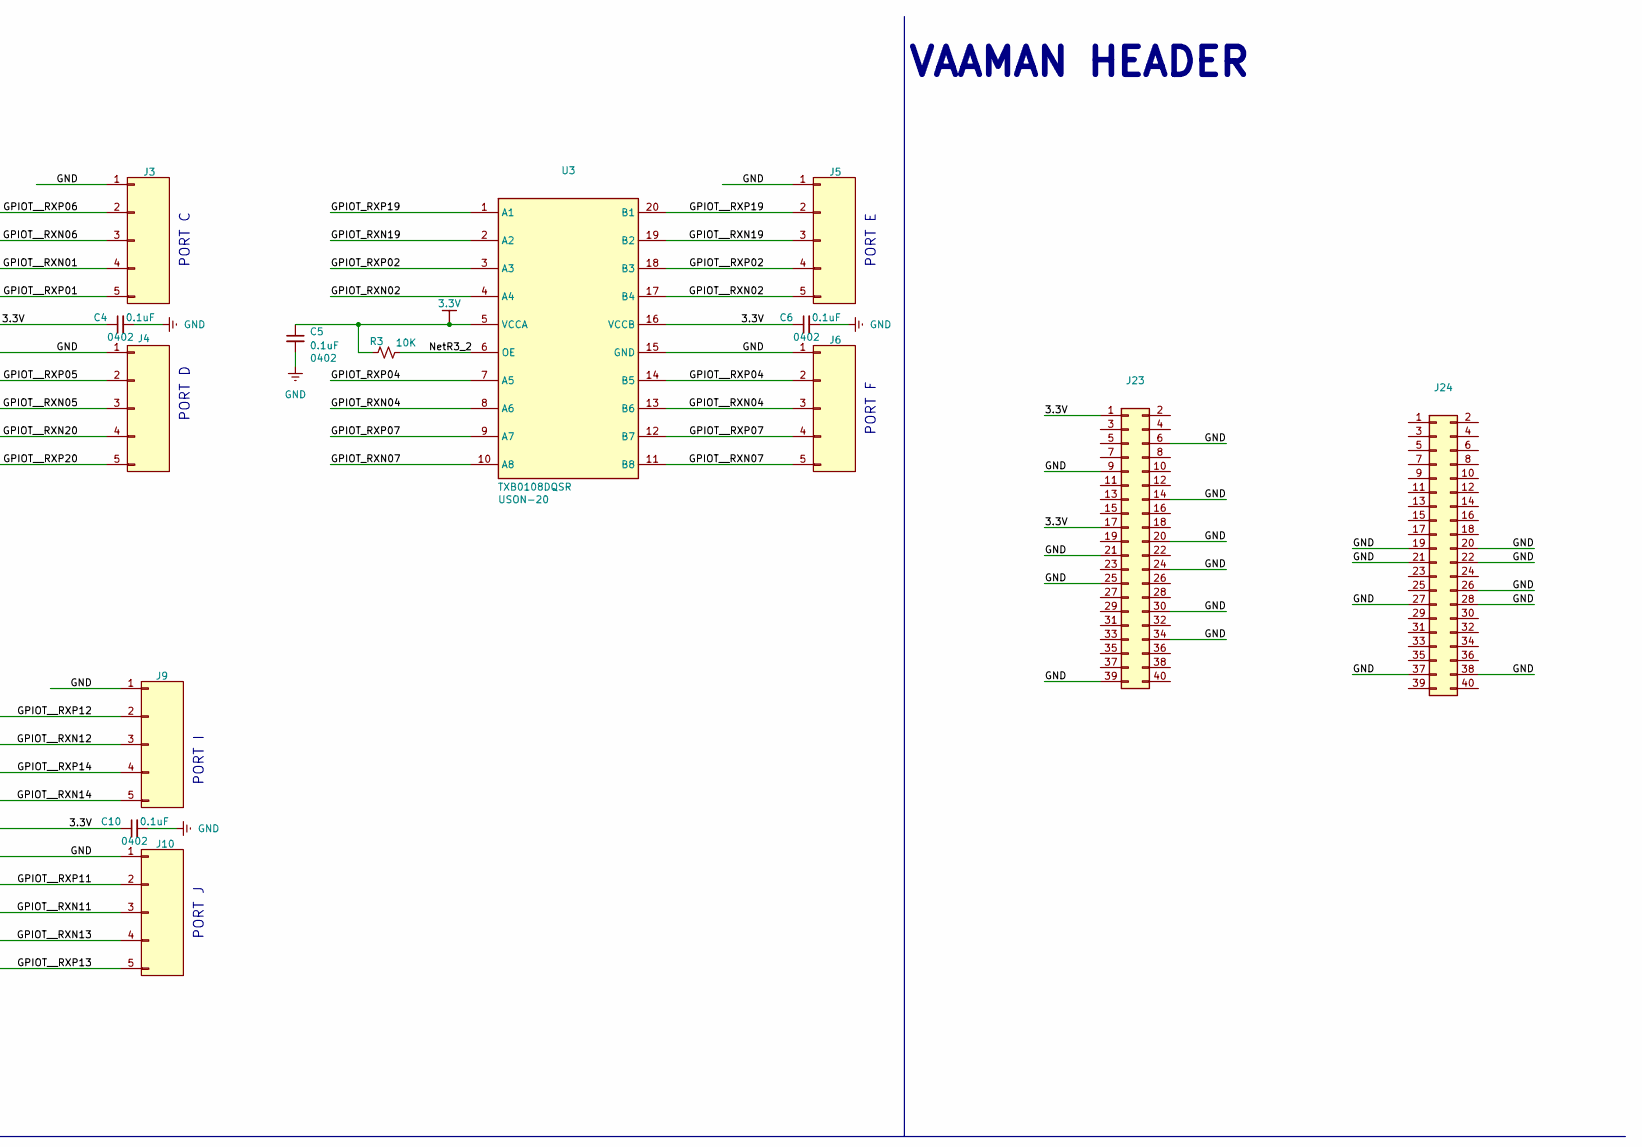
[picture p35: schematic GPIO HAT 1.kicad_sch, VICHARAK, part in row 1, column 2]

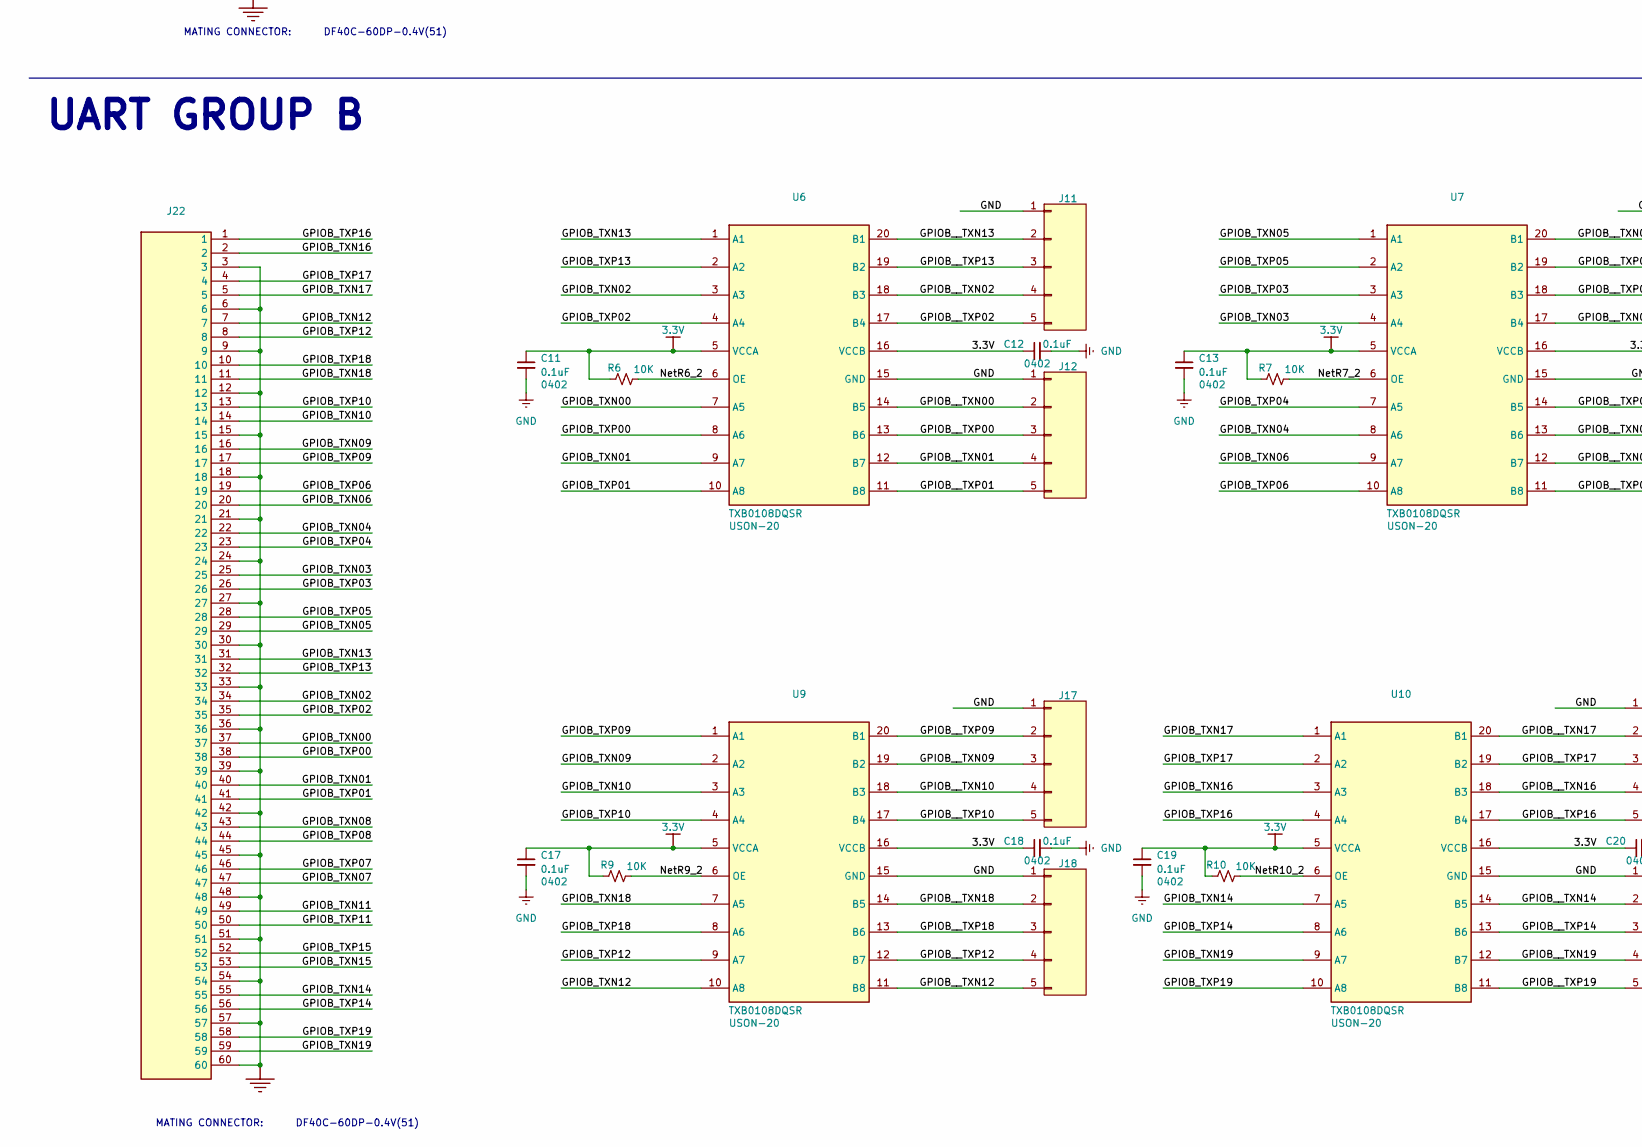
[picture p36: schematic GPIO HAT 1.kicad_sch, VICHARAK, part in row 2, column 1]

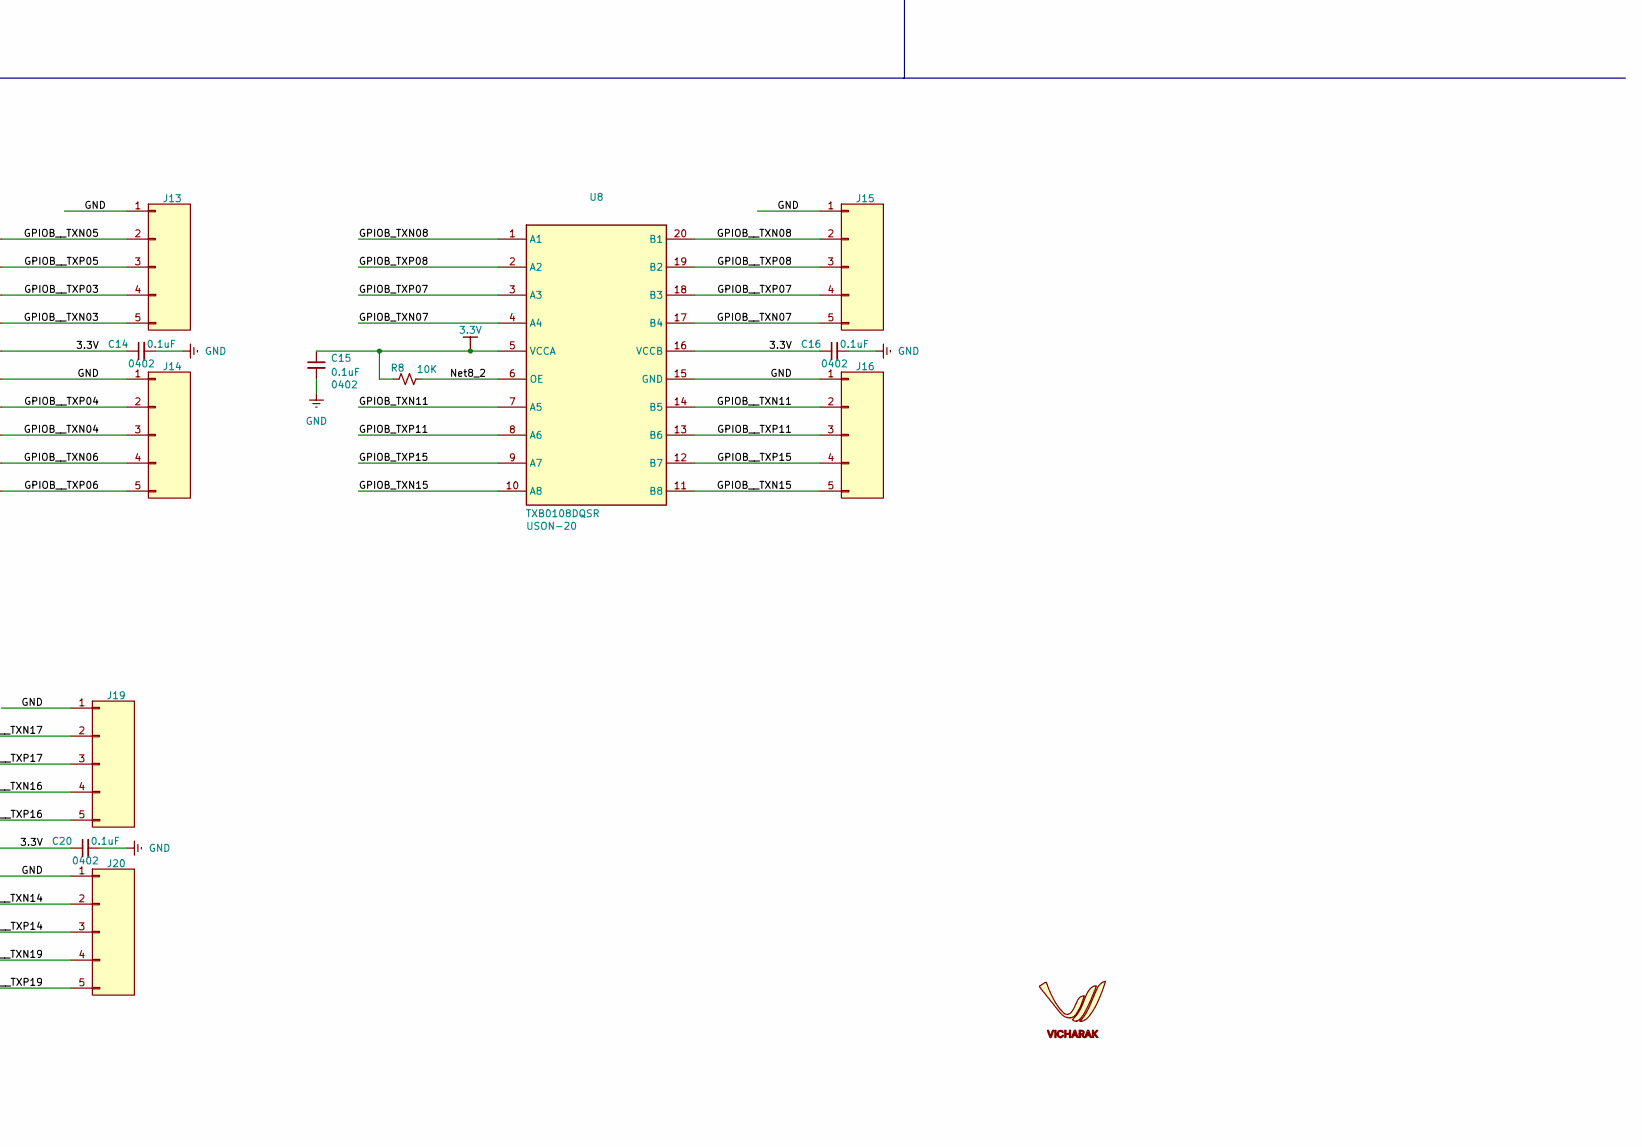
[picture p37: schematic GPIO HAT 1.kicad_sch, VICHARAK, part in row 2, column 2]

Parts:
C1, C2, C3, C4, C5, C6, C7, C8, C9, C10, C11, C12, C13, C14, C15, C16, C17, C18, C19, C20: 0.1uF; CAP0402
J1, J2, J3, J4, J5, J6, J7, J8, J9, J10, J11, J12, J13, J14, J15, J16, J17, J18, J19, J20: Conn_01x05; 01x05 Header 2.54mm
J21, J22: LVDS2; Mouser Part Number 798-DF40C60DS0.4V51
J23, J24: 2.54-2*20PPC104; 2x20 header; MANUFACTURER PART NUMBER 2.54-2*20PPC104
R1, R2, R3, R4, R5, R6, R7, R8, R9, R10: 10K; RES0402_10K
U1, U2, U3, U4, U5, U6, U7, U8, U9, U10: TXB0108DQSR; Mouser Part Number 595-TXB0108DQSR

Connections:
3.3V: C1.1, C2.1, C3.1, C4.1, C5.1, C6.1, C7.1, C8.1, C9.1, C10.1, C11.1, C12.1, C13.1, C14.1, C15.1, C16.1, C17.1, C18.1, C19.1, C20.1, J23.1, J23.17, R1.1, R2.1, R3.1, R4.1, R5.1, R6.1, R7.1, R8.1, R9.1, R10.1, U1.5 (VCCA), U1.16 (VCCB), U2.5 (VCCA), U2.16 (VCCB), U3.5 (VCCA), U3.16 (VCCB), U4.5 (VCCA), U4.16 (VCCB), U5.5 (VCCA), U5.16 (VCCB), U6.5 (VCCA), U6.16 (VCCB), U7.5 (VCCA), U7.16 (VCCB), U8.5 (VCCA), U8.16 (VCCB), U9.5 (VCCA), U9.16 (VCCB), U10.5 (VCCA), U10.16 (VCCB)
/GPIOB_TXN00: J22.37, U6.7 (A5)
/GPIOB_TXN01: J22.40, U6.9 (A7)
/GPIOB_TXN02: J22.34, U6.3 (A3)
/GPIOB_TXN03: J22.25, U7.4 (A4)
/GPIOB_TXN04: J22.22, U7.8 (A6)
/GPIOB_TXN05: J22.29, U7.1 (A1)
/GPIOB_TXN06: J22.20, U7.9 (A7)
/GPIOB_TXN07: J22.47, U8.4 (A4)
/GPIOB_TXN08: J22.43, U8.1 (A1)
/GPIOB_TXN09: J22.16, U9.2 (A2)
/GPIOB_TXN10: J22.14, U9.3 (A3)
/GPIOB_TXN11: J22.49, U8.7 (A5)
/GPIOB_TXN12: J22.7, U9.10 (A8)
/GPIOB_TXN13: J22.31, U6.1 (A1)
/GPIOB_TXN14: J22.55, U10.7 (A5)
/GPIOB_TXN15: J22.53, U8.10 (A8)
/GPIOB_TXN16: J22.2, U10.3 (A3)
/GPIOB_TXN17: J22.5, U10.1 (A1)
/GPIOB_TXN18: J22.11, U9.7 (A5)
/GPIOB_TXN19: J22.59, U10.9 (A7)
/GPIOB_TXP00: J22.38, U6.8 (A6)
/GPIOB_TXP01: J22.41, U6.10 (A8)
/GPIOB_TXP02: J22.35, U6.4 (A4)
/GPIOB_TXP03: J22.26, U7.3 (A3)
/GPIOB_TXP04: J22.23, U7.7 (A5)
/GPIOB_TXP05: J22.28, U7.2 (A2)
/GPIOB_TXP06: J22.19, U7.10 (A8)
/GPIOB_TXP07: J22.46, U8.3 (A3)
/GPIOB_TXP08: J22.44, U8.2 (A2)
/GPIOB_TXP09: J22.17, U9.1 (A1)
/GPIOB_TXP10: J22.13, U9.4 (A4)
/GPIOB_TXP11: J22.50, U8.8 (A6)
/GPIOB_TXP12: J22.8, U9.9 (A7)
/GPIOB_TXP13: J22.32, U6.2 (A2)
/GPIOB_TXP14: J22.56, U10.8 (A6)
/GPIOB_TXP15: J22.52, U8.9 (A7)
/GPIOB_TXP16: J22.1, U10.4 (A4)
/GPIOB_TXP17: J22.4, U10.2 (A2)
/GPIOB_TXP18: J22.10, U9.8 (A6)
/GPIOB_TXP19: J22.58, U10.10 (A8)
/GPIOB__TXN00: J12.2, U6.14 (B5)
/GPIOB__TXN01: J12.4, U6.12 (B7)
/GPIOB__TXN02: J11.4, U6.18 (B3)
/GPIOB__TXN03: J13.5, U7.17 (B4)
/GPIOB__TXN04: J14.3, U7.13 (B6)
/GPIOB__TXN05: J13.2, U7.20 (B1)
/GPIOB__TXN06: J14.4, U7.12 (B7)
/GPIOB__TXN07: J15.5, U8.17 (B4)
/GPIOB__TXN08: J15.2, U8.20 (B1)
/GPIOB__TXN09: J17.3, U9.19 (B2)
/GPIOB__TXN10: J17.4, U9.18 (B3)
/GPIOB__TXN11: J16.2, U8.14 (B5)
/GPIOB__TXN12: J18.5, U9.11 (B8)
/GPIOB__TXN13: J11.2, U6.20 (B1)
/GPIOB__TXN14: J20.2, U10.14 (B5)
/GPIOB__TXN15: J16.5, U8.11 (B8)
/GPIOB__TXN16: J19.4, U10.18 (B3)
/GPIOB__TXN17: J19.2, U10.20 (B1)
/GPIOB__TXN18: J18.2, U9.14 (B5)
/GPIOB__TXN19: J20.4, U10.12 (B7)
/GPIOB__TXP00: J12.3, U6.13 (B6)
/GPIOB__TXP01: J12.5, U6.11 (B8)
/GPIOB__TXP02: J11.5, U6.17 (B4)
/GPIOB__TXP03: J13.4, U7.18 (B3)
/GPIOB__TXP04: J14.2, U7.14 (B5)
/GPIOB__TXP05: J13.3, U7.19 (B2)
/GPIOB__TXP06: J14.5, U7.11 (B8)
/GPIOB__TXP07: J15.4, U8.18 (B3)
/GPIOB__TXP08: J15.3, U8.19 (B2)
/GPIOB__TXP09: J17.2, U9.20 (B1)
/GPIOB__TXP10: J17.5, U9.17 (B4)
/GPIOB__TXP11: J16.3, U8.13 (B6)
/GPIOB__TXP12: J18.4, U9.12 (B7)
/GPIOB__TXP13: J11.3, U6.19 (B2)
/GPIOB__TXP14: J20.3, U10.13 (B6)
/GPIOB__TXP15: J16.4, U8.12 (B7)
/GPIOB__TXP16: J19.5, U10.17 (B4)
/GPIOB__TXP17: J19.3, U10.19 (B2)
/GPIOB__TXP18: J18.3, U9.13 (B6)
/GPIOB__TXP19: J20.5, U10.11 (B8)
/GPIOT_RXN01: J21.56, U2.3 (A3)
/GPIOT_RXN02: J21.17, U3.4 (A4)
/GPIOT_RXN03: J21.2, U1.2 (A2)
/GPIOT_RXN04: J21.20, U3.8 (A6)
/GPIOT_RXN05: J21.52, U2.8 (A6)
/GPIOT_RXN06: J21.58, U2.2 (A2)
/GPIOT_RXN07: J21.23, U3.10 (A8)
/GPIOT_RXN08: J21.5, U1.4 (A4)
/GPIOT_RXN09: J21.40, U4.8 (A6)
/GPIOT_RXN11: J21.26, U5.8 (A6)
/GPIOT_RXN12: J21.34, U5.2 (A2)
/GPIOT_RXN13: J21.29, U5.9 (A7)
/GPIOT_RXN14: J21.31, U5.4 (A4)
/GPIOT_RXN15: J21.46, U4.2 (A2)
/GPIOT_RXN16: J21.43, U4.4 (A4)
/GPIOT_RXN17: J21.38, U4.9 (A7)
/GPIOT_RXN18: J21.11, U1.10 (A8)
/GPIOT_RXN19: J21.14, U3.2 (A2)
/GPIOT_RXN20: J21.50, U2.9 (A7)
/GPIOT_RXN21: J21.7, U1.7 (A5)
/GPIOT_RXP01: J21.55, U2.4 (A4)
/GPIOT_RXP02: J21.16, U3.3 (A3)
/GPIOT_RXP03: J21.1, U1.1 (A1)
/GPIOT_RXP04: J21.19, U3.7 (A5)
/GPIOT_RXP05: J21.53, U2.7 (A5)
/GPIOT_RXP06: J21.59, U2.1 (A1)
/GPIOT_RXP07: J21.22, U3.9 (A7)
/GPIOT_RXP08: J21.4, U1.3 (A3)
/GPIOT_RXP09: J21.41, U4.7 (A5)
/GPIOT_RXP11: J21.25, U5.7 (A5)
/GPIOT_RXP12: J21.35, U5.1 (A1)
/GPIOT_RXP13: J21.28, U5.10 (A8)
/GPIOT_RXP14: J21.32, U5.3 (A3)
/GPIOT_RXP15: J21.47, U4.1 (A1)
/GPIOT_RXP16: J21.44, U4.3 (A3)
/GPIOT_RXP17: J21.37, U4.10 (A8)
/GPIOT_RXP18: J21.10, U1.9 (A7)
/GPIOT_RXP19: J21.13, U3.1 (A1)
/GPIOT_RXP20: J21.49, U2.10 (A8)
/GPIOT_RXP21: J21.8, U1.8 (A6)
/GPIOT__RXN01: J3.4, U2.18 (B3)
/GPIOT__RXN02: J5.5, U3.17 (B4)
/GPIOT__RXN03: J1.3, U1.19 (B2)
/GPIOT__RXN04: J6.3, U3.13 (B6)
/GPIOT__RXN05: J4.3, U2.13 (B6)
/GPIOT__RXN06: J3.3, U2.19 (B2)
/GPIOT__RXN07: J6.5, U3.11 (B8)
/GPIOT__RXN08: J1.5, U1.17 (B4)
/GPIOT__RXN09: J8.3, U4.13 (B6)
/GPIOT__RXN11: J10.3, U5.13 (B6)
/GPIOT__RXN12: J9.3, U5.19 (B2)
/GPIOT__RXN13: J10.4, U5.12 (B7)
/GPIOT__RXN14: J9.5, U5.17 (B4)
/GPIOT__RXN15: J7.3, U4.19 (B2)
/GPIOT__RXN16: J7.5, U4.17 (B4)
/GPIOT__RXN17: J8.4, U4.12 (B7)
/GPIOT__RXN18: J2.5, U1.11 (B8)
/GPIOT__RXN19: J5.3, U3.19 (B2)
/GPIOT__RXN20: J4.4, U2.12 (B7)
/GPIOT__RXN21: J2.2, U1.14 (B5)
/GPIOT__RXP01: J3.5, U2.17 (B4)
/GPIOT__RXP02: J5.4, U3.18 (B3)
/GPIOT__RXP03: J1.2, U1.20 (B1)
/GPIOT__RXP04: J6.2, U3.14 (B5)
/GPIOT__RXP05: J4.2, U2.14 (B5)
/GPIOT__RXP06: J3.2, U2.20 (B1)
/GPIOT__RXP07: J6.4, U3.12 (B7)
/GPIOT__RXP08: J1.4, U1.18 (B3)
/GPIOT__RXP09: J8.2, U4.14 (B5)
/GPIOT__RXP11: J10.2, U5.14 (B5)
/GPIOT__RXP12: J9.2, U5.20 (B1)
/GPIOT__RXP13: J10.5, U5.11 (B8)
/GPIOT__RXP14: J9.4, U5.18 (B3)
/GPIOT__RXP15: J7.2, U4.20 (B1)
/GPIOT__RXP16: J7.4, U4.18 (B3)
/GPIOT__RXP17: J8.5, U4.11 (B8)
/GPIOT__RXP18: J2.4, U1.12 (B7)
/GPIOT__RXP19: J5.2, U3.20 (B1)
/GPIOT__RXP20: J4.5, U2.11 (B8)
/GPIOT__RXP21: J2.3, U1.13 (B6)
/Net8_2: R8.2, U8.6 (OE)
/NetR1_2: R1.2, U1.6 (OE)
/NetR2_2: R2.2, U2.6 (OE)
/NetR3_2: R3.2, U3.6 (OE)
/NetR4_2: R4.2, U4.6 (OE)
/NetR5_2: R5.2, U5.6 (OE)
/NetR6_2: R6.2, U6.6 (OE)
/NetR7_2: R7.2, U7.6 (OE)
/NetR9_2: R9.2, U9.6 (OE)
/NetR10_2: R10.2, U10.6 (OE)
GND: C1.2, C2.2, C3.2, C4.2, C5.2, C6.2, C7.2, C8.2, C9.2, C10.2, C11.2, C12.2, C13.2, C14.2, C15.2, C16.2, C17.2, C18.2, C19.2, C20.2, J1.1, J2.1, J3.1, J4.1, J5.1, J6.1, J7.1, J8.1, J9.1, J10.1, J11.1, J12.1, J13.1, J14.1, J15.1, J16.1, J17.1, J18.1, J19.1, J20.1, J21.3, J21.6, J21.9, J21.12, J21.15, J21.18, J21.21, J21.24, J21.27, J21.30, J21.33, J21.36, J21.39, J21.42, J21.45, J21.48, J21.51, J21.54, J21.57, J21.60, J22.3, J22.6, J22.9, J22.12, J22.15, J22.18, J22.21, J22.24, J22.27, J22.30, J22.33, J22.36, J22.39, J22.42, J22.45, J22.48, J22.51, J22.54, J22.57, J22.60, J23.6, J23.9, J23.14, J23.20, J23.21, J23.24, J23.25, J23.30, J23.34, J23.39, J24.19, J24.20, J24.21, J24.22, J24.26, J24.27, J24.28, J24.37, J24.38, U1.15 (GND), U2.15 (GND), U3.15 (GND), U4.15 (GND), U5.15 (GND), U6.15 (GND), U7.15 (GND), U8.15 (GND), U9.15 (GND), U10.15 (GND)

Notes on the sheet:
PORT C
MATING CONNECTOR:
PORT G
PORT I
DF40C-60DP-0.4V(51)
VAAMAN HEADER
UART GROUP B
PORT H
UART GROUP A
PORT D
PORT F
PORT B
PORT E
PORT J
PORT A



Board: 4 copper layers, 68.0 x 85.0 mm, 64 parts (22 on the bottom side), 172 nets.

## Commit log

2024-11-12 Version 1.0
    [GPIO HAT 1-B_Cu.gbr, GPIO HAT 1-B_Mask.gbr, GPIO HAT 1-B_Paste.gbr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]
2024-11-12 Version 1.1
    [GPIO HAT 2-B_Cu.gbr, GPIO HAT 2-B_Mask.gbr, GPIO HAT 2-B_Paste.gbr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]
2024-12-12 12V Jack removed and 5V USB added
2024-12-13 Ground plane added to top layer
    [GPIO HAT 2.kicad_pcb]
2024-12-13 BOM and Gerber Generated
    [GPIO HAT 2-B_Cu.gbr, GPIO HAT 2-B_Mask.gbr, GPIO HAT 2-B_Paste.gbr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]
2024-12-13 Update
    Gerber Generated
    [GPIO HAT 1-B_Cu.gbr, GPIO HAT 1-B_Mask.gbr, GPIO HAT 1-B_Paste.gbr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]
2024-12-24 Copper in layer 2 added
    [GPIO HAT 2-B_Cu.gbr, GPIO HAT 2-B_Mask.gbr, GPIO HAT 2-B_Paste.gbr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]
2025-03-26 GPIO number change, CC1 & CC2 tied to GND
    [GPIO HAT 2-B_Cu.gbr, GPIO HAT 2-B_Mask.gbr, GPIO HAT 2-B_Paste.gbr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]
2025-03-26 Gerber Generated
    [GPIO HAT 2-B_Cu.gbr, GPIO HAT 2-B_Mask.gbr, GPIO HAT 2-B_Paste.gbr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]
2025-03-26 Folder Change
    [GPIO HAT 2-B_Cu.gbr, GPIO HAT 2-B_Mask.gbr, GPIO HAT 2-B_Paste.gbr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]
2025-04-10 Gerber genrated
    Overlay 64 pin to 88 pin
    [GPIO HAT 2-B_Cu.gbr, GPIO HAT 2-B_Mask.gbr, GPIO HAT 2-B_Paste.gbr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]
2025-05-16 Project file generated
    BOM, HTML , PDFs
    [C_0402_1005Metric.step, C_0603_1608Metric.step, C_0805_2012Metric.step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]
2025-07-18 BOM and HTML Update
    [GPIO HAT 2.csv, GPIO HAT 2.kicad_pcb]

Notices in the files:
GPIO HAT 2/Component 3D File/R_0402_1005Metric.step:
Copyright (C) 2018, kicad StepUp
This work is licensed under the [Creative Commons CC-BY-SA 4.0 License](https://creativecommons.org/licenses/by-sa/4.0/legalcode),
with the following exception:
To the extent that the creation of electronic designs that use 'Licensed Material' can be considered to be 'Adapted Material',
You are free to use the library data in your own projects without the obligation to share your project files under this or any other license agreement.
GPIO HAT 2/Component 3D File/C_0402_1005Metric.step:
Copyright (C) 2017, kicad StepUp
